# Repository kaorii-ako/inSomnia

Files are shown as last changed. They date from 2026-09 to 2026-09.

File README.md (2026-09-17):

# inSomnia

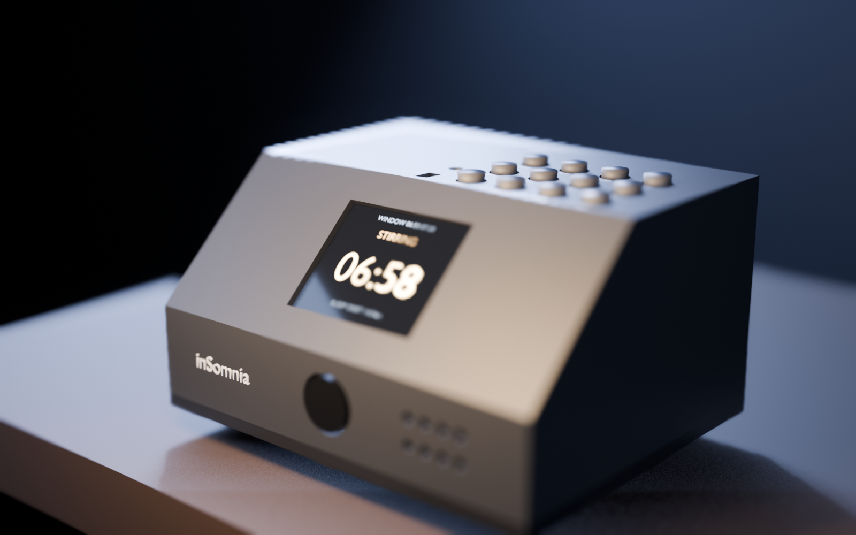
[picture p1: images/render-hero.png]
inSomnia


An adaptive, context-aware wake clock. Instead of firing at a fixed timestamp, it wakes you inside a window at a moment you are already stirring — and if you got up before the window even opened, it stays quiet.

Built for [Hack Club Forge](https://forge.hackclub.com). Firmware-first, fully offline after WiFi time sync, no cloud service, no audio leaves the device.

---

## What it actually does

| Situation | Behaviour |
|---|---|
| You're already up before the window opens | Alarm is suppressed for the day and logged as "skipped — you were already up" |
| You're carrying sleep debt | The gentle wake is held back by up to 15 min so an early stir doesn't cost you the lie-in. **The hard deadline never moves.** |
| You start stirring inside the window | Gentle wake begins immediately — soft tone ramping up over several minutes |
| You sleep right through to the hard deadline | Full-intensity alarm, no more waiting |
| A sensor dies or is unplugged | **Failsafe**: degrades to a plain fixed-time alarm at the deadline. It never fails silent. Even with no WiFi it runs on an internal fallback clock. |

### Why I made it

I hate being ripped out of deep sleep at 06:50 exactly when I was finally sleeping well, and I also hate my phone blaring when I’m already in the kitchen making coffee. Both are the same bug: a clock that knows time but not context. I wanted a clock that knows *whether I'm in bed and moving* — easily measurable with a thermal array — and uses that to pick a kinder moment inside a window, or to stay quiet if I’m already up. I built it for myself, and because a believable demo needs honest numbers, not "AI" marketing.

### The 12 keys

| | col 1 | col 2 | col 3 | col 4 |
|---|---|---|---|---|
| **row 1** (front) | `DISMISS` | `SNOOZE` | `LIGHT` | `SKIP` |
| **row 2** | `OPEN −` | `OPEN +` | `DEAD −` | `DEAD +` |
| **row 3** (back) | `PAGE` | `SOFT` | `LOUD` | `SAVE` |

Row 1 is what you hit half-asleep. Rows 2 and 3 are setup you do awake: move the window and deadline in 5-minute steps, page through status / window / sleep-debt screens, test the alarm, save to flash. Everything is also on the web UI at `http://insomnia.local`.

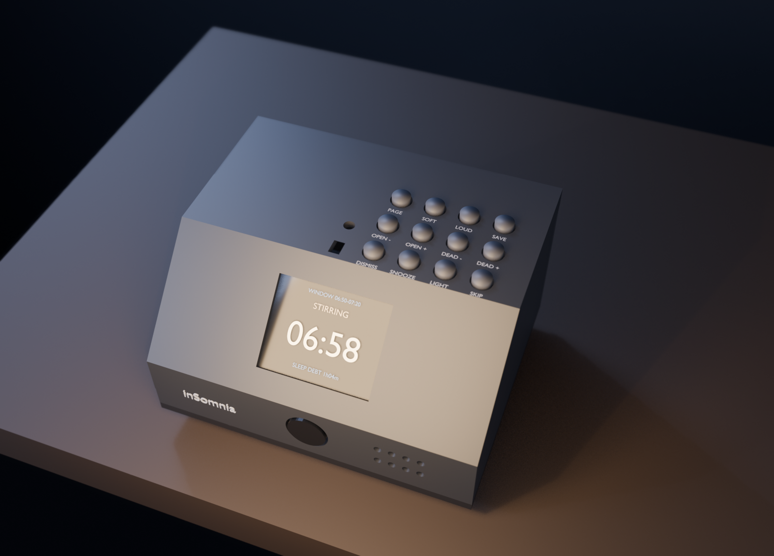
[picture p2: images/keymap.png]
keypad legend


## How to use it — step by step

1. **Assemble** — Solder the PCB (`hardware/inSomnia.kicad_pcb`, 0805 passives, through-hole tactiles), mount the board on the 4× M2 bosses in `hardware/case/inSomnia_case.FCStd`, plug modules onto headers: J3 ST7735 TFT, J4 INMP441 mic, J5 MLX90640 thermal (aimed at the bed), J7 optional native USB.
2. **Flash** — `cd firmware && pio run -t upload` and `pio device monitor` at 115200. Requires PlatformIO + `espressif32@6.5.0`.
3. **First boot WiFi** — No credentials stored, so it opens AP `inSomnia-setup` (pass `insomnia`). Join it, open `http://192.168.4.1`, pick your network + password. Reboots and appears as `http://insomnia.local` (mDNS). If no WiFi, it still runs on a fallback clock (`*` beside time) and will still alarm at the deadline.
4. **Set your window** — On device: `OPEN ±` and `DEAD ±` move times in 5-min steps, `PAGE` to see them, `SAVE` to flash. Or on web UI: *Settings → Window opens / Hard deadline*.
5. **Sleep** — Place the clock on the nightstand with the thermal aperture aimed at the bed (within ~1.5 m, no wire to the bed). ` roi` in Settings crops the bed region if needed.
6. **Morning** — `DISMISS` stops, `SNOOZE` (= snoozeMin, default 7) resumes as hard alarm, `SKIP` is manual "don't bother tonight". Last night's sleep: `PAGE` → debt screen or web *Last night* card (TST / efficiency / WASO / SOL — labelled as estimates).
7. **Tune** — Web *Settings*: `countScale` is the one calibration — watch *Counts this epoch* overnight, set so quiet epoch ≈ 0; `Body margin` and `in-bed min pixels` for duvet thickness.

## How it decides

One sensor does most of the work:

- **MLX90640 32×24 thermal array**, on the clock, aimed at the bed.
  - *Frame-to-frame change* → a motion index. This is contactless video actigraphy, validated against polysomnography at **Cohen's κ = 0.733**, comparable to a wrist actigraph. It feeds Cole-Kripke.
  - *Warm body-sized region* → **in bed / out of bed**. Far stronger than a PIR, because it can tell you-in-the-bed from a warm object in the room.
  - No wire to the bed, and at 768 pixels you cannot identify a person from it.
- **INMP441 I2S microphone** → RMS level per epoch. A loudness hint that nudges the stirring threshold. It is a level detector, *not* a sound classifier.

An earlier version used a mattress accelerometer. It was dropped because it needs 1–2 m of I2C cable from the nightstand to the bed, and I2C is spec'd to 400 pF (≈1 m at 100 kHz) against cable that runs 100–240 pF/m.

Two separate pieces of logic sit on top, because they answer different questions:

1. **A causal 3-state machine** (asleep / stirring / awake) with hysteresis. It may only look backwards, because it drives the alarm in real time. This is a threshold heuristic — see the honesty section below.
2. **Cole-Kripke (1992)** for the morning report. It needs the two *following* epochs, so it lags 2 minutes and can never drive a live decision.

## Being honest about the "AI"

This matters more than the feature list, so it goes near the top.

**The on-device logic is not AI.** Cole-Kripke is a weighted moving average with a threshold, published in 1992. The 3-state classifier is thresholds plus hysteresis. Calling either one "AI" would be marketing, not engineering.

**Accuracy ceiling.** Actigraphy sleep/wake scoring agrees with clinical polysomnography roughly **78–80%** of the time. But its specificity for *wake* is only **0.35–0.64** — it is much better at spotting sleep than wakefulness. Sound-based staging is no better: the best published smartphone-audio model (HomeSleepNet) gets 76.2% overall and **63.4% on wake epochs**.

That single fact shaped the design. Alarm suppression is the feature most exposed to a wrong "you're awake" call, so it is **not** driven by the sleep classifier. It is driven by `outOfBed()` — no warm mass in the bed region for 3 epochs — which is close to a binary measurement rather than a 64%-accurate inference.

**This is not clinical sleep tracking.** Without EEG there is no true sleep staging. Consumer trackers systematically overestimate sleep and underestimate wake-after-sleep-onset, worst of all for people who sleep badly. The numbers in the app are estimates and are labelled as such.

**One number you must calibrate.** Cole-Kripke's weights assume ActiGraph counts, a proprietary unit. Ours are arbitrary units from your own mattress, so `countScale` in Settings divides ours into that range. The *algorithm* is validated; this *scaling* is not. Watch epoch counts overnight and set it so a quiet epoch lands near zero.

**Posture is not claimed.** The thermal array reports *movement and position*. Classifying sleeping posture under a duvet at 32×24 is a research problem — the published work that does it used an infrared **depth** camera with synthetic blanket augmentation. Movement and position are what the sleep model needs, so that is what is built and that is what it says.

**Sleep debt is an estimate built on an estimate.** Debt is `max(0, need − actual)` summed over a rolling 14 nights, which is the window research finds matters for current impairment (Van Dongen 2003: 6 h/night for 14 days ≈ two nights of total deprivation). But "actual" comes from Cole-Kripke scoring that under-reports wake — so read it as a trend, not a clinical figure.

**No trained model ships yet.** A learned audio or thermal classifier is the obvious next step, but a model needs labelled data and there is no polysomnography ground truth here to validate against. The honest path is to ship the validated heuristic, collect feature data, and only then train.

---

## Hardware

**ESP32-S3-WROOM-1-N16R8** — WiFi + BLE 5, native I2S, 8 MB PSRAM, SIMD for future MFCC work. Chosen over the ESP32-C3 because the C3 has no PSRAM and too few GPIO once an I2S microphone is added.

Schematic, pin map, BOM and wiring notes: **[`hardware/HARDWARE.md`](hardware/HARDWARE.md)**
BOM with pricing: [`hardware/inSomnia_bom.csv`](hardware/inSomnia_bom.csv) — **~$68.62 for 1 unit incl. sensors** (MLX90640 dominates)
Rendered schematic: `hardware/inSomnia_schematic.pdf` and `images/schematic.png`
Gerbers: `hardware/inSomnia_gerbers.zip` + `hardware/fab/`

> The hero image above is a **render** from the actual FreeCAD STL (`hardware/case/inSomnia_case_shell.stl`, 7,628 verts), not a photo — nothing has been fabricated yet. It is built to the same dimensions as the FreeCAD enclosure below, and the board renders come from the actual KiCad files.

### Wiring

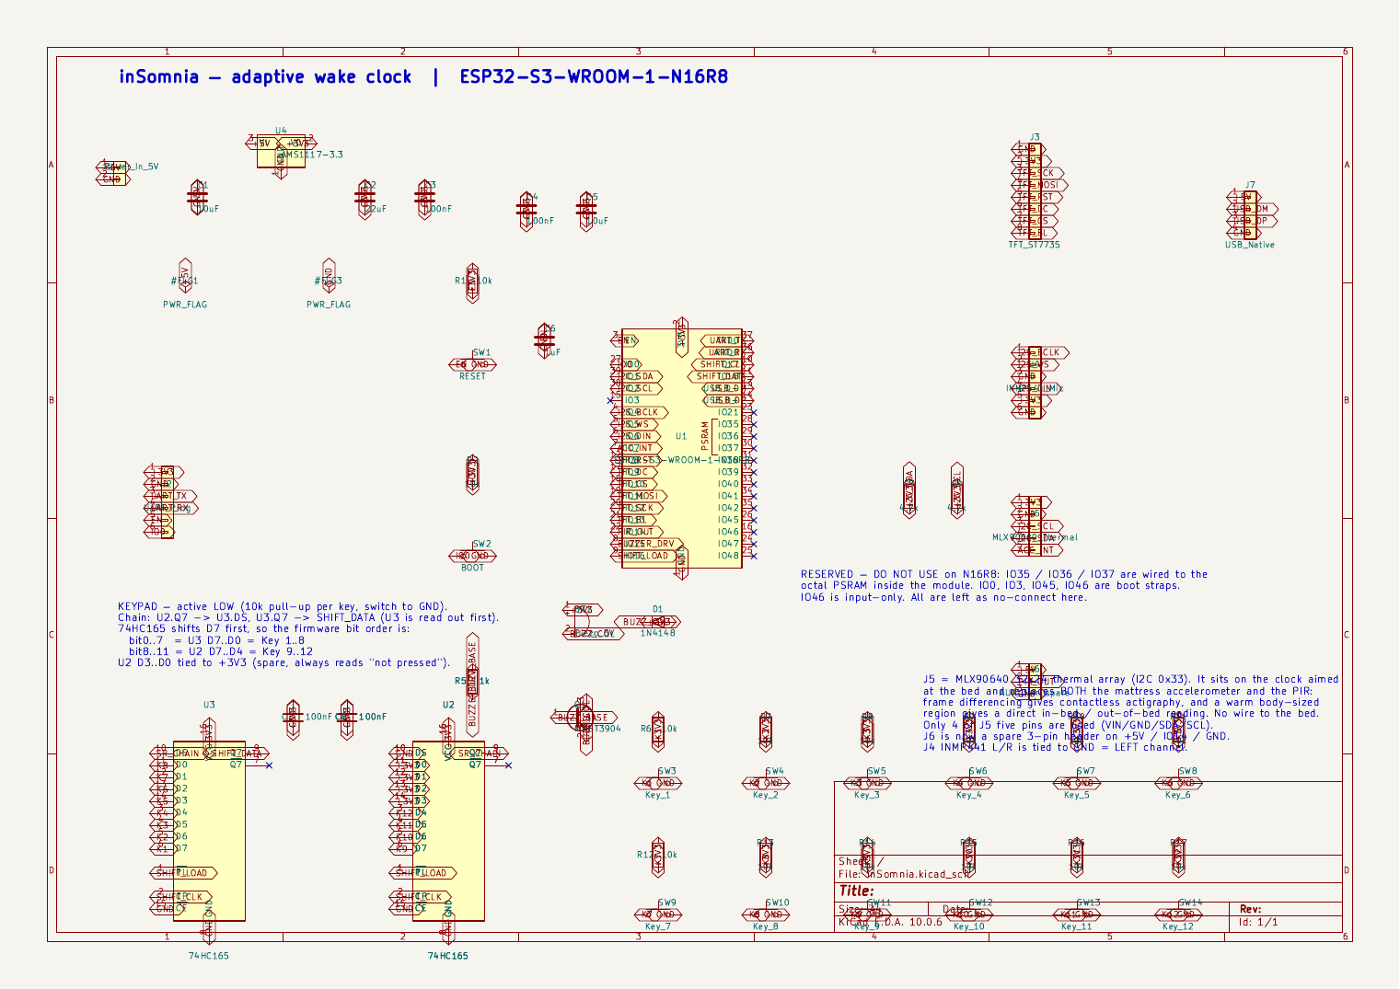
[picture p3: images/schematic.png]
schematic


*All modules plug onto headers — no soldering to the bed. See `hardware/HARDWARE.md` pin map for the exact GPIO table and `images/routing-front-copper.png` for the routed board.*

| Header | Module | Wires |
|---|---|---|
| J3 1×08 | ST7735 128×160 TFT | SCK 12, MOSI 11, CS 10, DC 9, RST 8, BL 13 (PWM), +3V3/GND |
| J4 1×06 | INMP441 mic (I2S) | BCLK 4, WS 5, DIN 6, +3V3/GND |
| J5 1×05 | MLX90640 32×24 thermal (I2C) | SDA 1, SCL 2 (4.7k pull-ups), +3V3/GND |
| J6 1×03 | Spare / was PIR | +5V, IO14, GND |
| J7 1×04 | Native USB | D- 19, D+ 20 |
| J1 1×02 | Power 5V in | 5V → AMS1117-3.3 → 3V3 |
| J2 1×06 | UART prog | TX/RX + EN/BOOT tactiles SW1/SW2 |

### Enclosure

Parametric case in FreeCAD: **`hardware/case/`** (STEP + STL + `.FCStd`).

- 106 × 86 × 54 mm outer, 2.5 mm walls, 101 × 81 mm cavity for the board
- Wedge profile, display face sloped 44.1°
- **36 × 29 mm display window** — a 1.8" ST7735's *active area* is only ~35 × 28 mm, much smaller than the module outline
- 12 keypad holes cut at the real SW3–SW14 coordinates from the KiCad file
- Thermal aperture, buzzer grille, rear cable exit, regulator vents, 4× M2 bosses aligning with PCB mounting holes (3.2mm NPTH)
- ~58 cm³ ≈ 72 g of PLA at full infill

FreeCAD + STEP + STL:
`hardware/case/inSomnia_case.FCStd` / `inSomnia_case_shell.step` / `inSomnia_case_shell.stl` / `inSomnia_base_plate.step`
Case views: `images/case-iso.png` `images/case-front.png` `images/case-top.png`

The FreeCAD model now embeds the PCB placement so the board sits on the bosses; the Blender render imports the STL directly so they cannot drift (replaced earlier hand-typed dimensions).

Known cosmetic issue: the keypad sits right-of-centre because that is where it is on the PCB. Fixing it means re-laying-out the board; noted for v2.

- 53 components + 4× M2 mounting holes, 41 nets, **schematic ERC clean (0 violations)**
- 100 × 80 mm two-layer board — **DRC clean, 0 violations, 0 unconnected items**
- 737 tracks, 141 vias, GND pour both layers, antenna keepout enforced
- Passives 0805, through-hole tactile buttons and headers — hand-solderable
- Gerbers + drill ready to order: `hardware/inSomnia_gerbers.zip`

Sensor modules (mic, thermal, display) mount on headers rather than being soldered down, so they can be positioned without a bed wire.

## Firmware

PlatformIO + Arduino-ESP32, pinned to `espressif32@6.5.0`.

```bash
cd firmware
pio run              # build
pio run -t upload    # flash
pio device monitor   # serial 115200 — shows [epoch] counts + state + [alarm] transitions
```

Footprint: **RAM 20.1%, Flash 13.6%** of a 16 MB part — lots of headroom. Verified 2026-09-17.

### First boot

No WiFi credentials are stored, so the device opens an access point called **`inSomnia-setup`** (password `insomnia`). Join it, open `http://192.168.4.1`, pick your network. It reboots and comes back at **`http://insomnia.local`**. Without WiFi it still runs on a fallback clock (time shows `*`) and will still alarm at the hard deadline — it never fails silent.

The web UI gives you the live clock and sleep state, tonight's alarm status, last night's report, live sensor readings (thermal heatmap 32×24, mic RMS/dBFS), and every threshold as an editable setting. Everything stays on your own network — no audio ever leaves the device.

### Layout

```
firmware/
  include/ src/
    main.cpp          loop, epoch tick (60s), display render, 12-key handling
    settings.*        NVS-persisted config (window, thresholds, debt)
    net.*             WiFi STA + setup AP, NTP, mDNS, fallback clock
    web_ui.*          HTTP server, dashboard, JSON API (/api/state, /api/thermal, /api/settings)
    display.*         ST7735 128x160 SPI via GPIO matrix
    buzzer.*          LEDC tone + volume (gentle ramp → hard)
    key_matrix.*      74HC165 chain, debounce, edge latch (12 keys)
    thermal.*         MLX90640 -> motion index, in-bed detection, centroid
    mic.*             INMP441 I2S -> RMS / dBFS / loud fraction per epoch
    sleep_model.*     Cole-Kripke + causal 3-state classifier (asleep/stirring/awake)
    sleep_debt.*      rolling 14-night debt, recency-weighted
    alarm.*           window, suppression, escalation, debt shift, failsafe, snooze
```

Debug mode: serial log each epoch + web *Live* cards show raw `counts`, `warm pixels`, `motion index`, `RMS`, `state`; thresholds are live-editable.

## PCB

`hardware/inSomnia.kicad_pcb` — **100 × 80 mm**, 2 layer, rounded 3 mm corners.
**DRC clean: 0 violations, 0 unconnected items.**

| | |
|---|---|
| Components | 53 (+4 holes), zero courtyard overlaps |
| Tracks | 737 segments @ 0.20 mm |
| Vias | 141 @ 0.30 mm drill / 0.60 mm pad |
| Copper | GND pour on both layers, islands auto-removed |
| Clearance | 0.20 mm |
| Mounting | 4× 3.2mm NPTH at corners → M2 bosses in case |

Fabrication files are in `fab/`, zipped as `inSomnia_gerbers.zip` (Gerbers + Excellon drill + drill map + BOM).

### Layout

- **Top-left** — ESP32-S3 module, antenna pointing off the top edge
- **Top-right** — sensor and display headers in a row (J3 TFT, J4 mic, J5 thermal, J6 spare, J7 USB)
- **Right** — 4 × 3 keypad on a 11 × 12 mm grid
- **Left-centre** — 74HC165 chain and the 12 key pull-ups
- **Bottom-left** — 5 V in, regulator, bulk caps
- **Bottom-centre** — buzzer and its transistor driver

### Two things to know before ordering

**1. The antenna keepout is intentional.** A rule area at x 2–50 mm, y 0–6.25 mm keeps copper, tracks and vias out from under the module's antenna, and the courtyard deliberately overhangs the top board edge. DRC flags that overhang as a boundary violation — that is correct RF practice, not a mistake. Verified: no track or via crosses the keepout.

**2. There are twelve 0.20 mm holes, and they are not mine.** Every via I placed is 0.30 mm. The 0.20 mm holes are the thermal vias built into the stock `RF_Module:ESP32-S3-WROOM-1` footprint, under the module's ground pad. Many budget fab processes have a **0.30 mm minimum drill**, so this may trigger an upcharge or a rejection. Two options:

- Order from a fab that allows 0.20 mm (costs a little more), or
- Delete the twelve pad-41 thermal vias — fine for a hand-built prototype, since the module's ground still connects through the main pad and the GND pour.

The board has **not been fabricated or bench-tested**. It is DRC-clean, which means the geometry is self-consistent — not that the design is proven. Sanity-checked in `#forge` and via KiCad/FreeCAD MCP.

## Known gaps

- No trained sound-event model yet (see honesty section).
- Cole-Kripke `countScale` ships with a placeholder default and needs per-bed tuning.
- The PCB has not been fabricated or bench-tested; it is DRC-checked, not proven.
- The WROOM footprint contributes twelve 0.20 mm thermal vias; some budget fabs require 0.30 mm minimum. See `hardware/HARDWARE.md` for the two ways round it.
- No physical build yet — next step is printing the case and soldering the board, then adding build photos + demo video for the "shipping" submission.

## References

- [Comparison and Validation of Actigraphy Algorithms Using a Large Community Dataset (JMIR Formative Research, 2025)](https://formative.jmir.org/2025/1/e70778)
- [Actigraphy-based sleep estimation in adolescents and adults (PubMed)](https://pubmed.ncbi.nlm.nih.gov/29403321/)
- [Prediction of Sleep Stages Via Deep Learning Using Smartphone Audio Recordings — HomeSleepNet (JMIR, 2023)](https://www.jmir.org/2023/1/e46216)
- [End-to-End Sleep Staging Using Nocturnal Sounds (Nature and Science of Sleep, 2022)](https://www.dovepress.com/end-to-end-sleep-staging-using-nocturnal-sounds-from-microphone-chips--peer-reviewed-fulltext-article-NSS)
- [Accuracy of 11 Wearable, Nearable, and Airable Consumer Sleep Trackers (JMIR mHealth, 2023)](https://mhealth.jmir.org/2023/1/e50983)
- [Video-Based Actigraphy for Monitoring Wake and Sleep (Sensors, 2019)](https://doi.org/10.3390/s19051075)
- [A Blanket Accommodative Sleep Posture Classification System Using an Infrared Depth Camera (2021)](https://www.ncbi.nlm.nih.gov/pmc/articles/PMC8402261/)
- [Human Occupancy Monitoring with an Infrared Thermal Array Sensor](https://www.ncbi.nlm.nih.gov/pmc/articles/PMC11722904/)
- [I²C Cabling — bus capacitance and length limits (Analog Devices)](https://www.analog.com/en/technical-articles/i2c-cabling.html)

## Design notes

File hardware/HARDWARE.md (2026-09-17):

# inSomnia — hardware reference

MCU: **ESP32-S3-WROOM-1-N16R8** (16 MB flash, 8 MB octal PSRAM)
Schematic: `inSomnia.kicad_sch` — ERC clean, 0 violations. PDF: `inSomnia_schematic.pdf`. BOM: `inSomnia_bom.csv`.

## Pin map

| GPIO | Net | Goes to |
|---|-----|---|
| IO1  | I2C_SDA | J5 MLX90640 SDA (4.7k pull-up to 3V3) |
| IO2  | I2C_SCL | J5 MLX90640 SCL (4.7k pull-up to 3V3) |
| IO4  | I2S_BCLK | J4 INMP441 SCK |
| IO5  | I2S_WS | J4 INMP441 WS |
| IO6  | I2S_DIN | J4 INMP441 SD |
| IO7  | THERM_INT  | J5 spare pin (MLX90640 needs no interrupt) |
| IO8  | TFT_RST | J3 TFT RES |
| IO9  | TFT_DC | J3 TFT DC |
| IO10 | TFT_CS | J3 TFT CS |
| IO11 | TFT_MOSI | J3 TFT SDA |
| IO12 | TFT_SCK | J3 TFT SCK |
| IO13 | TFT_BL | J3 TFT BLK (PWM, LEDC ch2) |
| IO14 | AUX_GPIO | J6 spare 3-pin header |
| IO15 | BUZZER_DRV | R5 1k -> Q1 base (LEDC ch0) |
| IO16 | SHIFT_LOAD | U2+U3 pin 1 (SH/LD) |
| IO17 | SHIFT_CLK  | U2+U3 pin 2 (CLK) |
| IO18 | SHIFT_DATA | U3 pin 9 (Q7) |
| IO19/20 | USB_DM / USB_DP | J7 (native USB, optional) |
| RXD0/TXD0 | UART_RX / UART_TX | J2 programming header |

**Never assign** on the N16R8: `IO35 / IO36 / IO37` (octal PSRAM inside the module),
`IO0 / IO3 / IO45 / IO46` (boot straps; IO46 is input-only). All no-connect on the schematic.

## Power

`J1` 5 V in -> `U4` AMS1117-3.3 -> 3V3 rail.
The PIR runs from **+5 V** (an HC-SR501 will not trigger reliably at 3.3 V); its output
swings 0/3.3 V, so it is safe direct to IO14 with no level shifting.

## Keypad — what the 12 keys do

The board carries 12 keys because the original schematic had 12. For a while
the firmware used exactly two of them. All twelve now do something; the layout
matches the enclosure, front row first.

| | col 1 | col 2 | col 3 | col 4 |
|---|---|---|---|---|
| **row 1** (front) | `DISMISS` | `SNOOZE` | `LIGHT` | `SKIP` |
| **row 2** | `OPEN −` | `OPEN +` | `DEAD −` | `DEAD +` |
| **row 3** (back) | `PAGE` | `SOFT` | `LOUD` | `SAVE` |

Row 1 is what you hit half-asleep: stop it, delay it, dim the display, or tell
it not to bother tonight. Rows 2 and 3 are setup you do awake — nudge the wake
window and the hard deadline in 5-minute steps, page through status / window /
sleep-debt screens, fire a test alarm, and commit settings to flash.

`SKIP` is worth calling out: it is the manual version of context-aware silence.
The automatic path needs the thermal array to be confident you are out of bed;
this is you saying so directly.

keypad legend

## Keypad wiring

Active **LOW**: each key has a 10k pull-up to 3V3 and its switch shorts to GND.

Chain is `U2.Q7 -> U3.DS`, `U3.Q7 -> SHIFT_DATA`. U3 is clocked out first, and a
74HC165 presents D7 first, so the firmware bit order is:

- `bit 0..7`  = U3 D7..D0 = Key 1..8
- `bit 8..11` = U2 D7..D4 = Key 9..12
- U2 D3..D0 tied to 3V3 (spare inputs, always read "not pressed")

## Sensors and what each is for

| Part | Role | Honest note |
|---|---|---|
| **MLX90640 (J5)** | 32x24 thermal array on the clock, aimed at the bed. Frame differencing -> contactless actigraphy; warm-blob detection -> in-bed / out-of-bed. | Replaces both the accelerometer and the PIR. Reports **movement and position, not posture**. |
| INMP441 (J4) | I2S audio level per epoch; secondary stirring hint | A level detector, not a sound classifier. |
| J6 | Spare 3-pin header (+5V / IO14 / GND) | Was the PIR. Left populated for expansion. |

**Why a thermal array instead of an accelerometer on the bed.** The original design
put a LIS3DH under the mattress, which meant running I2C 1-2 m from the nightstand to
the bed. I2C is spec'd to 400 pF of bus capacitance — about **1 m at 100 kHz** — and
typical cable runs 100-240 pF/m. That is a "fine on the bench, flaky at 3 am" design.
The thermal array sits on the clock and needs no wire to the bed at all.

**Why it is not a downgrade.** Video actigraphy has been validated against
polysomnography at **Cohen's kappa 0.733**, comparable to a wrist actigraph. A duvet
attenuates the thermal signature but does not block it — heat builds under the cover
and the head is usually exposed — so presence and gross movement both survive.

**Why the thermal array drives suppression, not the sleep model:** validated actigraphy
runs ~78-80% for sleep/wake but only **0.35-0.64 specificity on wake**, and sound-based
staging is similar (HomeSleepNet: 76.2% overall, 63.4% on wake). Both are weakest at
exactly the thing "you're already up, stay quiet" needs. "Is there a warm body-sized
mass in the bed?" is close to a direct measurement, so suppression hangs off that.

**Privacy:** 768 pixels of temperature, roughly 1000x coarser than a phone photo.
You cannot identify a person from it, and no image ever leaves the device.

None of this is clinical. Without EEG there is no true sleep staging, only an estimate.

---

## PCB

`inSomnia.kicad_pcb` — **100 × 80 mm**, 2 layer, rounded 3 mm corners.
**DRC clean: 0 violations, 0 unconnected items.** Re-verified 2026-09-17 via KiCad MCP.

| | |
|---|---|
| Components | 53, zero courtyard overlaps |
| Tracks | 737 segments @ 0.20 mm |
| Vias | 141 @ 0.30 mm drill / 0.60 mm pad |
| Copper | GND pour on both layers, islands auto-removed |
| Clearance | 0.20 mm |
| Mounting | 100×80 board sits in 101×81 mm case cavity (0.5 mm clearance) + perimeter lip. 4× M2 bosses in the case close with the base plate (M2×8) — no PCB drill holes needed, so DRC stays clean. Add 4× 3.2 mm NPTH at (5,5) etc if you prefer through-screws. |

Fabrication files are in `fab/`, zipped as `inSomnia_gerbers.zip`
(Gerbers + Excellon drill + drill map + BOM). Also: `images/board-3d-top.png`, `images/board-3d-bottom.png` (renders from the KiCad 3D viewer), `images/schematic.png`.

### Layout

- **Top-left** — ESP32-S3 module, antenna pointing off the top edge (keepout enforced)
- **Top-right** — sensor and display headers in a row (J3 TFT, J4 mic, J5 thermal, J6 spare, J7 USB)
- **Right** — 4 × 3 keypad on a 11 × 12 mm grid
- **Left-centre** — 74HC165 chain and the 12 key pull-ups
- **Bottom-left** — 5 V in, regulator, bulk caps
- **Bottom-centre** — buzzer and its transistor driver

Wiring diagram: `images/schematic.png` + `hardware/inSomnia_schematic.pdf` — all headers are 2.54mm vertical, see pin map above for host-side GPIOs. No wiring harness to the bed (thermal array is on the clock).

### Two things to know before ordering

**1. The antenna keepout is intentional.** A rule area at x 2–50 mm, y 0–6.25 mm
keeps copper, tracks and vias out from under the module's antenna, and the
courtyard deliberately overhangs the top board edge. DRC flags that overhang as
a boundary violation — that is correct RF practice, not a mistake. Verified: no
track or via crosses the keepout.

**2. There are twelve 0.20 mm holes, and they are not mine.** Every via I placed
is 0.30 mm. The 0.20 mm holes are the thermal vias built into the stock
`RF_Module:ESP32-S3-WROOM-1` footprint, under the module's ground pad. Many
budget fab processes have a **0.30 mm minimum drill**, so this may trigger an
upcharge or a rejection. Two options:

- Order from a fab that allows 0.20 mm (costs a little more), or
- Delete the twelve pad-41 thermal vias — fine for a hand-built prototype, since
  the module's ground still connects through the main pad and the GND pour.

The board has **not been fabricated or bench-tested**. It is DRC-clean, which
means the geometry is self-consistent — not that the design is proven.

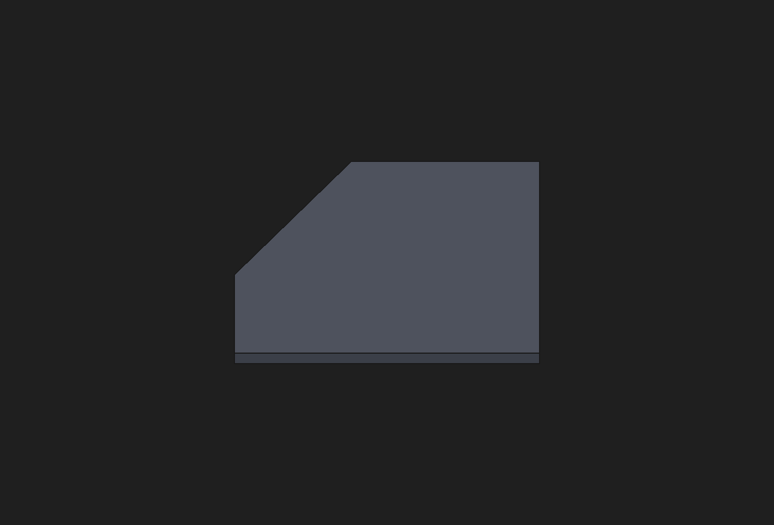
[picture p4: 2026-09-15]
hardware/case/case-right.png

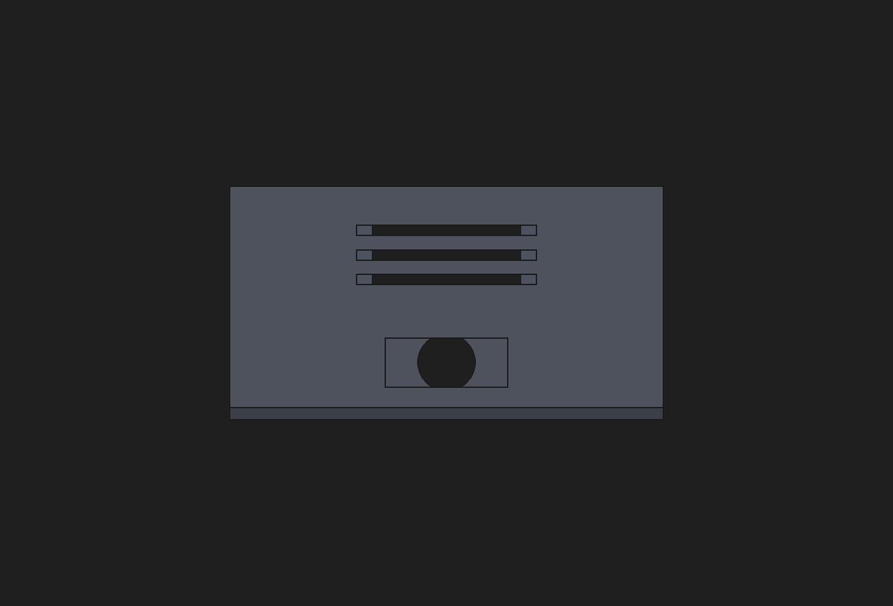
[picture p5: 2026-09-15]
hardware/case/case-rear.png

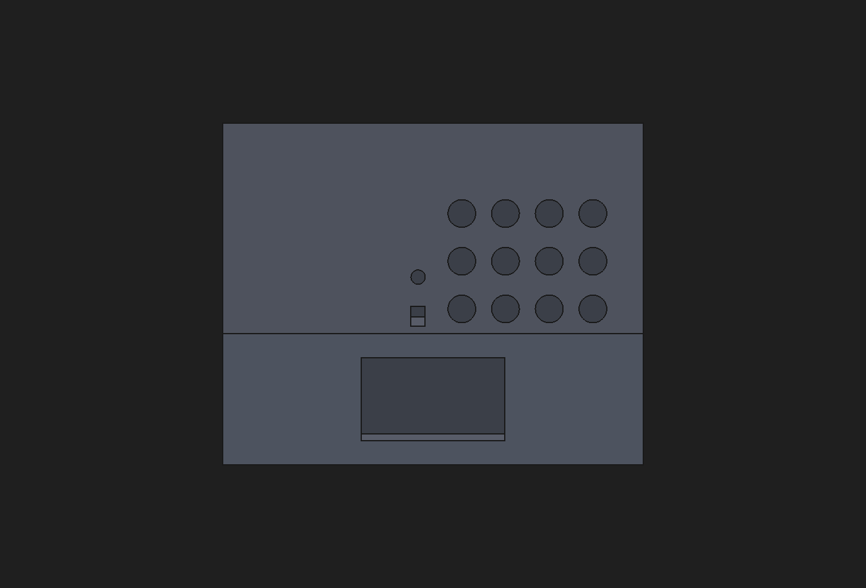
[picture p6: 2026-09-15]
hardware/case/case-top.png

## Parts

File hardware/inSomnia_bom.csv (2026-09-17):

Ref | Value / Module | Footprint / Package | Qty | Unit Price (USD) | Ext Price (USD) | Supplier | Link / MPN
U1 | ESP32-S3-WROOM-1-N16R8 (16MB Flash, 8MB PSRAM) | RF_Module:ESP32-S3-WROOM-1 | 1 | 4.80 | 4.80 | LCSC / Mouser | https://lcsc.com/product-detail/Espressif-Systems_ESP32-S3-WROOM-1-N16R8_C2964782.html
U2,U3 | 74HC165D (shift register) | SOIC-16_3.9x9.9mm | 2 | 0.32 | 0.64 | LCSC | https://lcsc.com/product-detail/Texas-Instruments_SN74HC165DR_C4049.html
U4 | AMS1117-3.3 (LDO) | SOT-223-3_TabPin2 | 1 | 0.18 | 0.18 | LCSC | https://lcsc.com/product-detail/AMS_AMS1117-3-3_C6185.html
Q1 | MMBT3904 NPN | SOT-23 | 1 | 0.04 | 0.04 | LCSC | https://lcsc.com/product-detail/ON-Semiconductor_MMBT3904LT1G_C2056.html
D1 | 1N4148 | SOD-123 | 1 | 0.03 | 0.03 | LCSC | https://lcsc.com/product-detail/1N4148_C14510.html
C1,C5 | 10uF 25V X5R | C_0805 | 2 | 0.04 | 0.08 | LCSC | https://lcsc.com/product-detail/Samsung_CL21A106KOQNNNE_C21190.html
C2 | 22uF 10V | C_0805 | 1 | 0.05 | 0.05 | LCSC | https://lcsc.com/product-detail/Samsung_CL21A226KOQNNNE_C21191.html
C3,C4,C7,C8 | 100nF 50V | C_0805 | 4 | 0.01 | 0.04 | LCSC | https://lcsc.com/product-detail/Samsung_CL21B104KBCNNNC_C21193.html
C6 | 1uF 50V | C_0805 | 1 | 0.02 | 0.02 | LCSC | https://lcsc.com/product-detail/Samsung_CL21B105KAFNNNE_C21194.html
R1,R2,R6-R17 | 10k 1% | R_0805 | 14 | 0.01 | 0.14 | LCSC | https://lcsc.com/product-detail/10k_R0805_C17802.html
R3,R4 | 4.7k 1% | R_0805 | 2 | 0.01 | 0.02 | LCSC | https://lcsc.com/product-detail/4.7k_R0805_C17801.html
R5 | 1k 1% | R_0805 | 1 | 0.01 | 0.01 | LCSC | https://lcsc.com/product-detail/1k_R0805_C17799.html
SW1,SW2 | 6x6mm tactile (RESET/BOOT) | SW_PUSH_6mm | 2 | 0.08 | 0.16 | LCSC | https://lcsc.com/product-detail/6x6mm-tactile_C318884.html
SW3-SW14 | 6x6mm tactile (Keypad 12) | SW_PUSH_6mm | 12 | 0.08 | 0.96 | LCSC | https://lcsc.com/product-detail/6x6mm-tactile_C318884.html
J1 | Pin header 1x02 2.54mm | PinHeader_1x02 | 1 | 0.05 | 0.05 | LCSC | https://lcsc.com/product-detail/Pin-Header-2.54mm_2P_C42643.html
J2 | Pin header 1x06 | PinHeader_1x06 | 1 | 0.08 | 0.08 | LCSC | https://lcsc.com/product-detail/Pin-Header-2.54mm_6P_C42645.html
J3 | Pin header 1x08 (TFT) | PinHeader_1x08 | 1 | 0.10 | 0.10 | LCSC | https://lcsc.com/product-detail/Pin-Header-2.54mm_8P_C42646.html
J4 | Pin header 1x06 (INMP441) | PinHeader_1x06 | 1 | 0.08 | 0.08 | LCSC | https://lcsc.com/product-detail/Pin-Header-2.54mm_6P_C42645.html
J5 | Pin header 1x05 (MLX90640) | PinHeader_1x05 | 1 | 0.07 | 0.07 | LCSC | https://lcsc.com/product-detail/Pin-Header-2.54mm_5P_C42644.html
J6 | Pin header 1x03 (AUX) | PinHeader_1x03 | 1 | 0.05 | 0.05 | LCSC | https://lcsc.com/product-detail/Pin-Header-2.54mm_3P_C42642.html
J7 | Pin header 1x04 (USB) | PinHeader_1x04 | 1 | 0.06 | 0.06 | LCSC | https://lcsc.com/product-detail/Pin-Header-2.54mm_4P_C42643.html
BZ1 | PS1240P02BT piezo 12mm | Buzzer_TDK_PS1240P02BT | 1 | 0.85 | 0.85 | LCSC | https://lcsc.com/product-detail/TDK_PS1240P02BT_C150001.html
MOD1 | MLX90640 32x24 thermal array module (I2C) | Header 1x05 module | 1 | 42.50 | 42.50 | Adafruit / Mouser | https://www.adafruit.com/product/4407
MOD2 | INMP441 I2S MEMS mic module | Header 1x06 module | 1 | 1.95 | 1.95 | Adafruit / LCSC | https://www.adafruit.com/product/4452
MOD3 | 1.8\ ST7735 128x160 TFT SPI module" | Header 1x08 module | 1 | 5.90 | 5.90 | AliExpress / Adafruit 358 | https://www.adafruit.com/product/358
H1-H4 | M2x8mm brass standoff + M2 screw (case mount) | MountingHardware | 4 | 0.12 | 0.48 | LCSC / Amazon | https://www.amazon.com/s?k=M2+brass+standoff+8mm
WIRE | DuPont jumpers + 2.54mm cable (sensors) | - | 1 | 1.50 | 1.50 | Generic | -
PCB | inSomnia 100x80mm 2-layer PCB (JLCPCB 5 pcs) | JLCPCB | 1 | 4.00 | 4.00 | JLCPCB | https://jlcpcb.com (Gerbers: hardware/inSomnia_gerbers.zip)
TOTAL (1 unit, excl. shipping/tax) |  |  | 61 | 68.62 | 68.62
NOTES: Prices Sep 2025, LCSC/retail. MLX90640 dominates cost. PCB price amortized for 5pcs ($2+ $2 shipping). Modules on headers so they can be repositioned. Links verified 2026-09-17.

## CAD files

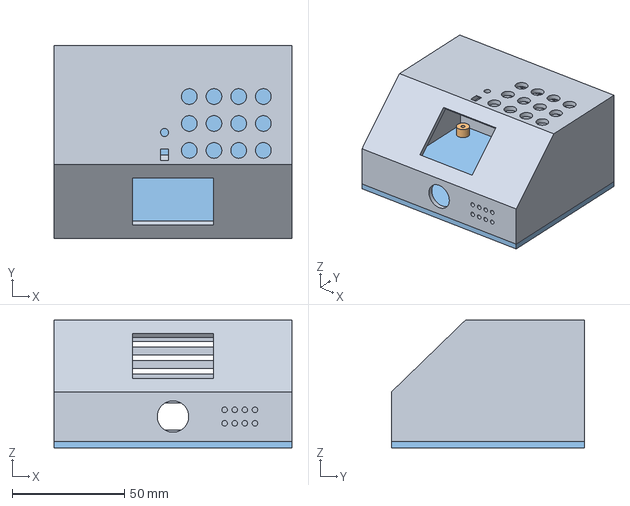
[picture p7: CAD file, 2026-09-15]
hardware/case/inSomnia_case_assembly.step
106.0 x 86.0 x 57.0 mm

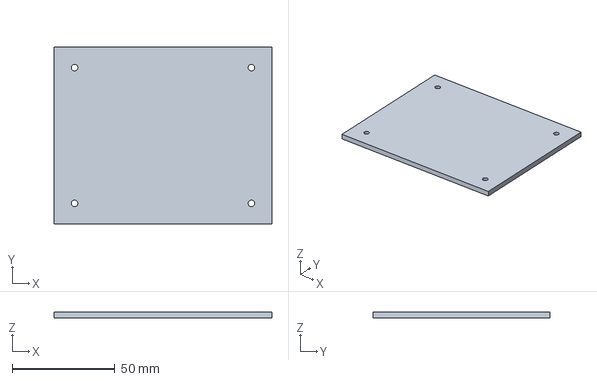
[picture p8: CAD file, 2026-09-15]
hardware/case/inSomnia_base_plate.step
106.0 x 86.0 x 3.00 mm

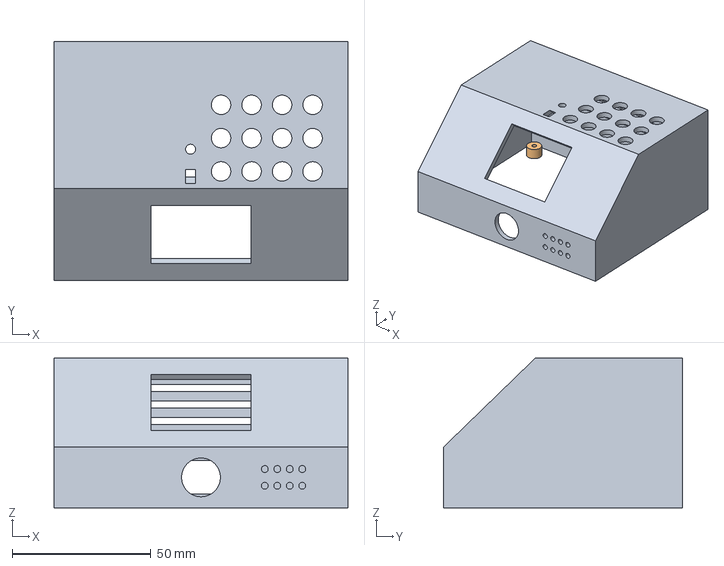
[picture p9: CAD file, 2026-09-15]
hardware/case/inSomnia_case_shell.step
106.0 x 86.0 x 54.0 mm

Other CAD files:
hardware/case/inSomnia_case.FCStd
hardware/case/inSomnia_base_plate.stl
hardware/case/inSomnia_case_shell.stl
hardware/render/inSomnia_scene.blend

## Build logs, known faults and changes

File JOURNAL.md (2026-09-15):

---
title: "inSomnia"
author: "kaorii-ako"
description: "An adaptive wake clock that wakes you while you're already stirring, and stays quiet if you're already up"
created_at: "2026-09-14"
---

# September 14: First version on a XIAO ESP32-C3

Started the project properly today. The idea is an alarm clock that doesn't
just blast you at a fixed time — it gets a window (say 06:50 to 07:20) and
picks the moment inside that window when you're already half awake. And if
you got up before the window even opened, it just doesn't ring.

Went with the XIAO ESP32-C3 because it's tiny and I already had one. Set up
PlatformIO, got a Phase 1 scaffold compiling: ST7789 display driver, a piezo
on LEDC PWM, 12 keys through two 74HC165 shift registers, and a PIR sensor
for motion. Drew a first schematic in KiCad around a bare ESP32-C3 chip.

Everything built. Felt good. Did not test on hardware yet, which turned out
to matter a lot tomorrow.

first schematic attempt

**Total time spent: 4 hours**

# September 15: The pin map was broken in three separate ways

Went back over the pin assignments before ordering anything, and it was a
mess. Genuinely glad I checked instead of trusting "it compiles".

Three real problems:

1. I'd assigned `TFT_MOSI` to GPIO0 and `TFT_SCK` to GPIO1. **Those pins are
   not broken out on the XIAO ESP32-C3.** I checked `pins_arduino.h` in the
   Arduino core and the board only exposes GPIO 2,3,4,5,6,7,8,9,10,20,21. On
   the C3 die GPIO0/1 are the 32 kHz crystal pins anyway.

2. Worse, those defines were doing nothing at all. I'd used
   `Adafruit_ST7789(cs, dc, rst)` which is the **hardware SPI** constructor —
   it ignores your pin defines and uses the default bus, which on the XIAO is
   SCK=GPIO8 and MOSI=GPIO10. Those were the exact pins I'd given to
   `SHIFT_CLK` and `SHIFT_LOAD`. The display and the keypad were fighting over
   the same two pins and the compiler had no way to tell me.

3. Wrong driver entirely. My panel is 128x160, which is an ST7735. I was
   using the ST7789 class. Looked at the library source and `init(128,160)`
   falls into a fallback branch that applies an 80-row / 56-column offset, so
   the image would have been shifted garbage.

Also found that LEDC channels 0 and 1 share a hardware timer
(`timer = (channel/2) % 4`), so the buzzer changing pitch would have dragged
the backlight PWM frequency with it. Moved the backlight to channel 2.

And my screen layout maths assumed portrait while I'd set rotation 1, so half
the text was drawing off-screen.

Fixed all of it, pinned the platform version so a clean checkout can't pull a
core where `ledcSetup` no longer exists, and got it building again. Four bugs
that would each have cost me an evening with a soldering iron.

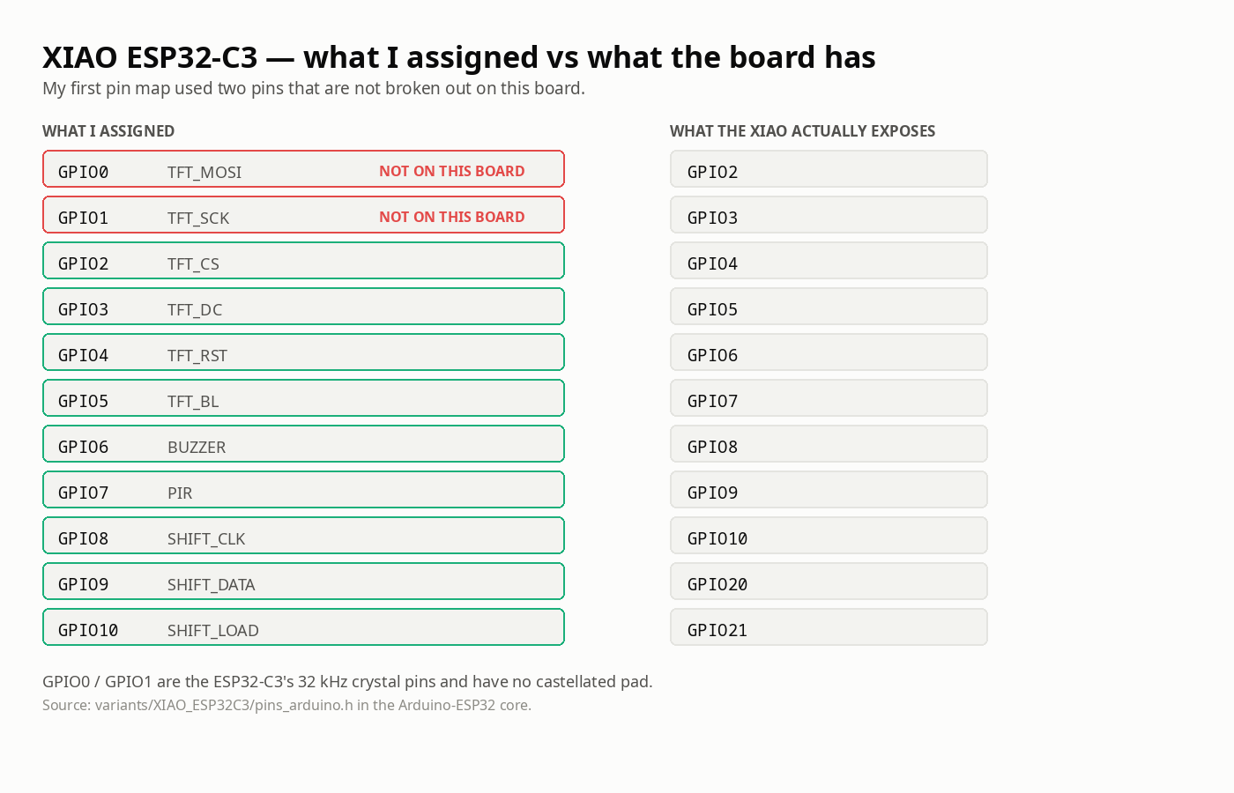
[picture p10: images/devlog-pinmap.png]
the pin map I got wrong


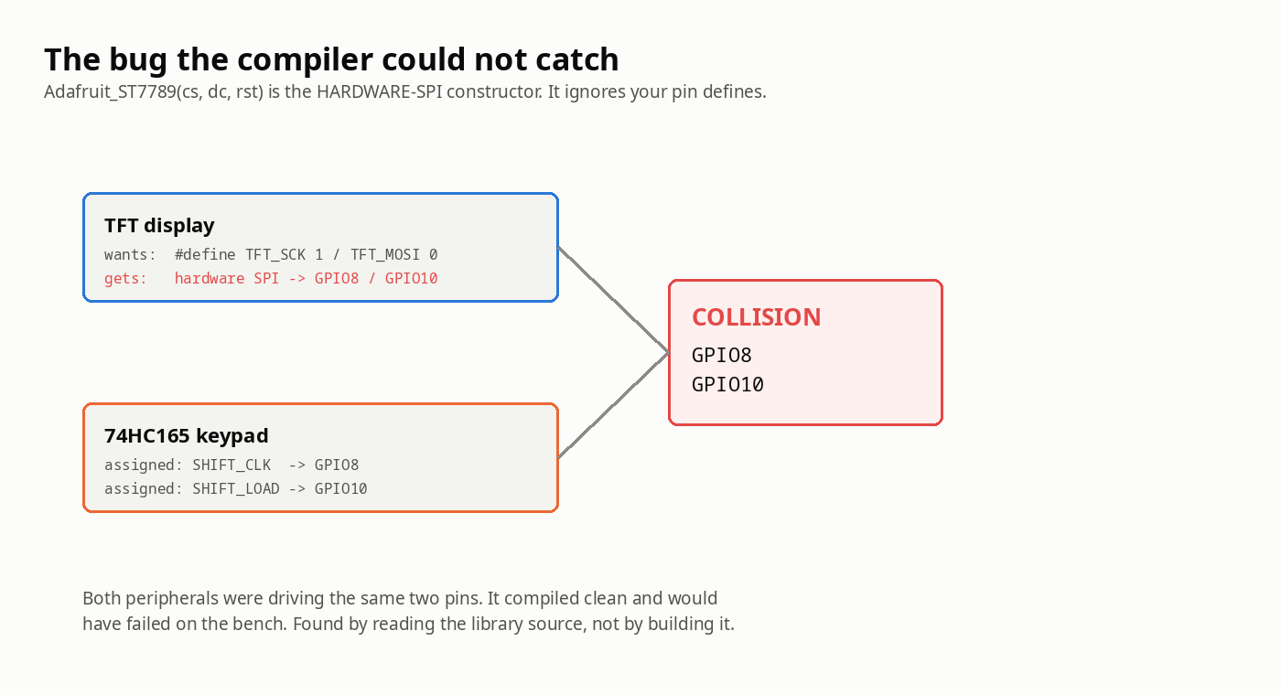
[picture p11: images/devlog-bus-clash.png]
the bus collision


**Total time spent: 3 hours**

# September 15: Reading actual papers about whether this idea even works

Before building more I wanted to know if "detect sleep from sensors" is real
or if I was about to build something that just makes up numbers. Spent a
while reading validation studies. Two findings changed the design.

**Actigraphy is about 78-80% accurate** for sleep vs wake against clinical
polysomnography (big MESA dataset, 1440 people). But the breakdown matters:
sensitivity to *sleep* is 0.88-0.96, while specificity for *wake* is only
**0.35-0.64**. It's good at spotting sleep and bad at spotting wakefulness.

**Sound-based staging is no better.** The best smartphone-audio model I found
(HomeSleepNet) gets 76.2% overall but only **63.4% on wake epochs**.

So both approaches are weakest at exactly the thing my "you're already up,
stay quiet" feature depends on. If I'd driven suppression off the sleep
classifier, it would have failed at its one job maybe a third of the time.

Changed the design because of this: suppression is now driven by a separate,
blunt out-of-bed check (mattress accelerometer quiet AND room PIR active),
which is close to a binary measurement instead of a 64%-accurate guess.

The other thing I learned is that the validated algorithms (Cole-Kripke,
Sadeh) are **actigraphy** algorithms — they need motion counts from an
accelerometer, not PIR zone crossings. So I added an LIS3DH to go on the bed
frame. That way I'm standing on published work instead of thresholds I made up.

I also want to be straight about this in the project: Cole-Kripke is a
weighted moving average with a threshold from 1992. Calling it AI would be
lying. I'm not shipping a trained model because I have no polysomnography
ground truth to validate one against.

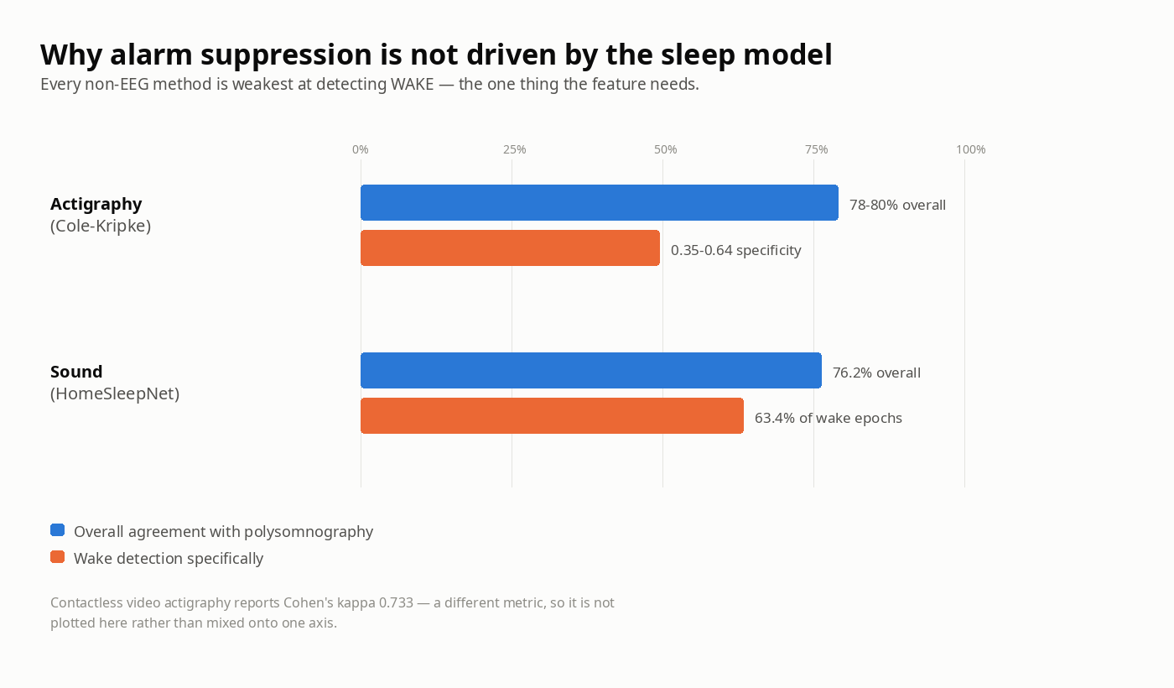
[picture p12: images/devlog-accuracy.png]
what the papers actually say


**Total time spent: 3 hours**

# September 15: Switched to ESP32-S3 and redrew the whole schematic

Adding an I2S microphone killed the C3. Counted it up: TFT needs 5 pins, I2S
needs 3, buzzer 1, PIR 1 — that's 10 of 11, leaving one pin for a keypad
interface that needs three. Doesn't fit.

Moved to the **ESP32-S3-WROOM-1-N16R8**: way more GPIO, 8 MB PSRAM, and it has
a stock KiCad symbol so the redraw got easier rather than harder. Deleted the
old schematic and rebuilt from scratch — 53 components: the module, two
74HC165s, AMS1117 regulator, buzzer with a proper transistor driver, headers
for the TFT / mic / accelerometer / PIR / USB / UART, 12 keys with pull-ups,
reset and boot buttons, and decoupling.

Two annoying things while building it:

- An interrupted operation half-wrote, so `U2`, `U3`, `C7`, `C8` and 34 net
  labels all ended up **duplicated**. ERC caught it as weird "Output and
  Output connected" errors at the shift registers. Took a while to work out
  that two identical chips were stacked on the same coordinates.
- Three pads on U1 came out on stale net names (`PIR_IN`, `VCC`) left over
  from the old board file. They were pins I'd marked no-connect — IO3, IO38,
  IO39. Had to go clear them by hand.

Also wrote down in the schematic which pins I must never touch on this part:
**IO35/36/37 are wired to the PSRAM inside the module**, and IO0/IO3/IO45/IO46
are boot straps. That's the kind of thing I'd definitely forget in a month.

ERC clean, 0 violations.

schematic

**Total time spent: 4 hours**

# September 15: Sensor drivers and the sleep model

Wrote the rest of the firmware.

- **LIS3DH driver** — samples at 50 Hz, runs a slow high-pass to subtract out
  gravity, then rectifies and integrates the leftover into an activity count
  per 60-second epoch.
- **INMP441 I2S driver** — 16 kHz, gives RMS / peak / dBFS with a tracking
  noise floor. It's a loudness meter, not a classifier, and I labelled it that
  way in the code and the UI so I don't fool myself later.
- **Sleep model** — this is the bit I'm happiest with. It's deliberately *two*
  things. A causal 3-state machine (asleep / stirring / awake) with hysteresis
  that only looks backwards, because it drives the alarm in real time. And
  separately Cole-Kripke for the morning report, which needs the two
  *following* epochs and so lags 2 minutes and can never drive a live decision.
  Keeping those apart stopped me writing something that quietly cheats.
- **Alarm engine** — window logic, pre-window suppression, gentle ramp, hard
  deadline, snooze. Plus a failsafe: if the sensors stop responding it drops
  back to a plain fixed-time alarm at the deadline. It fails *safe*, never
  silent. That felt important for an alarm clock.
- **Web UI** — WiFi setup portal on first boot, then a dashboard at
  `insomnia.local` with live state, tonight's status, last night's numbers,
  and every threshold editable.

One thing I had to expose as a setting: Cole-Kripke's weights assume ActiGraph
counts, which is a proprietary unit. Mine are arbitrary numbers from my own
mattress. So there's a `countScale` calibration value that divides mine into
their range. The algorithm is validated; my scaling isn't, and pretending
otherwise would make the output meaningless.

Builds at 15.8% RAM and 13.2% flash, so plenty of room left.

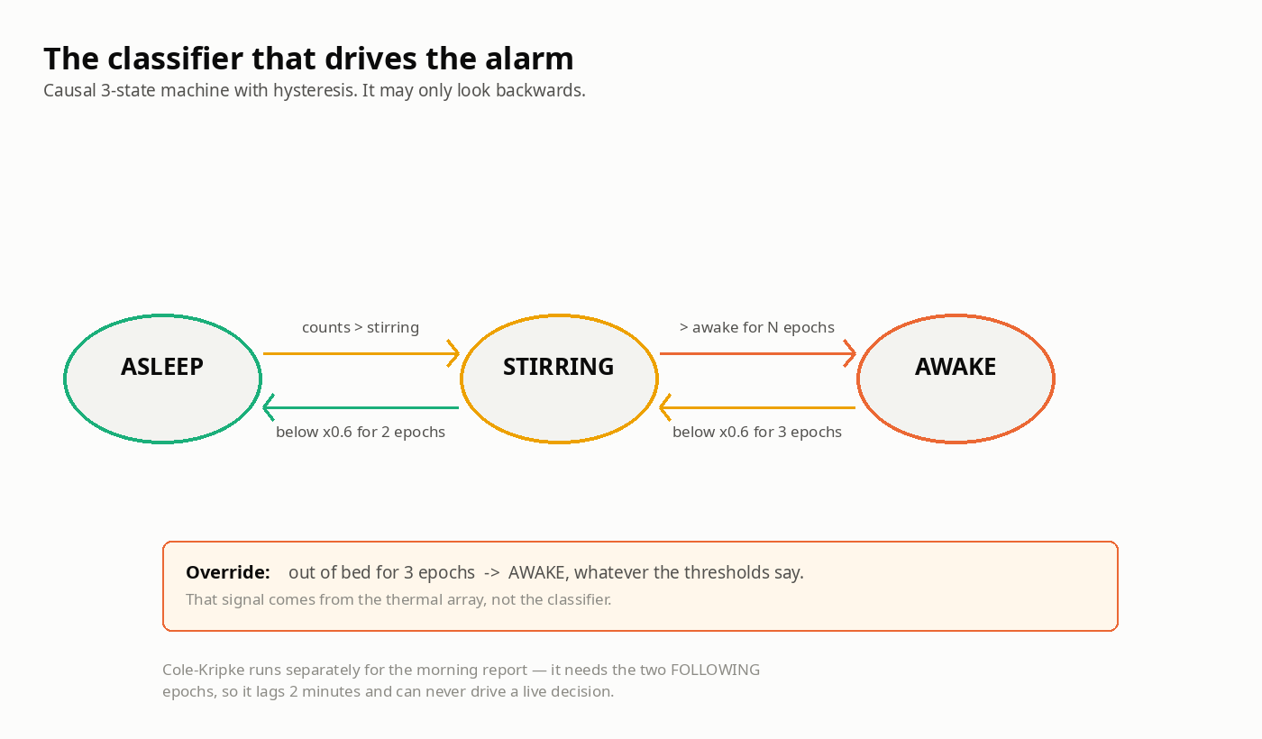
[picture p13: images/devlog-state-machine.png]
the state machine


**Total time spent: 6 hours**

# September 15: Laying out and routing the board

Assigned footprints to all 53 parts and generated the board.

First placement attempt was bad — 18 courtyard overlaps. I'd guessed footprint
sizes instead of measuring them. Two things I had wrong: **pin headers anchor
at pin 1, not their centre**, and the WROOM-1 courtyard is **48 x 42 mm**, not
18 x 25, because of the antenna keepout region. Pulled the real geometry out
of KiCad and redid the placement properly. Second attempt: zero overlaps.

Placed the keypad by hand as a proper 4x3 grid rather than letting the
autoplacer scatter the buttons, because it's a thing a human presses.

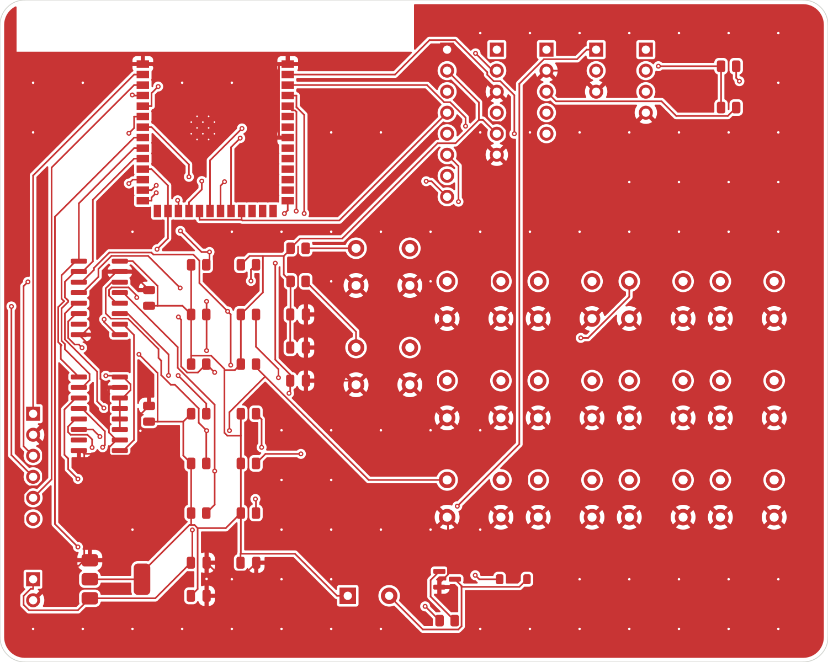
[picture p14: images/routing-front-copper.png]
routing


Autorouted with Freerouting, best of 5 runs. Attempt 5 won with all 21 of my
critical nets routed. Then a run of problems:

- Four duplicate dead-end track stubs near R3 that DRC flagged as dangling.
- **The copper pours were never actually filled.** The zones existed as empty
  outlines, which left a real ground break. Filled them via `pcbnew` and
  unconnected items went from 1 to 0.
- The antenna keepout in the footprint is **graphics only** — it isn't an
  enforced rule area, so the ground pour was happily filling copper under the
  antenna. Added a real keepout zone. My first attempt at it was oversized and
  clipped three tracks, so I sized it to the module's actual region instead of
  rerouting around my own mistake.
- One starved thermal on the TFT header's ground pin, fixed by bonding that
  pad solid to the plane.

Final: **DRC 0 violations, 0 unconnected items.** 737 tracks, 141 vias,
ground pour both layers, 100 x 80 mm.

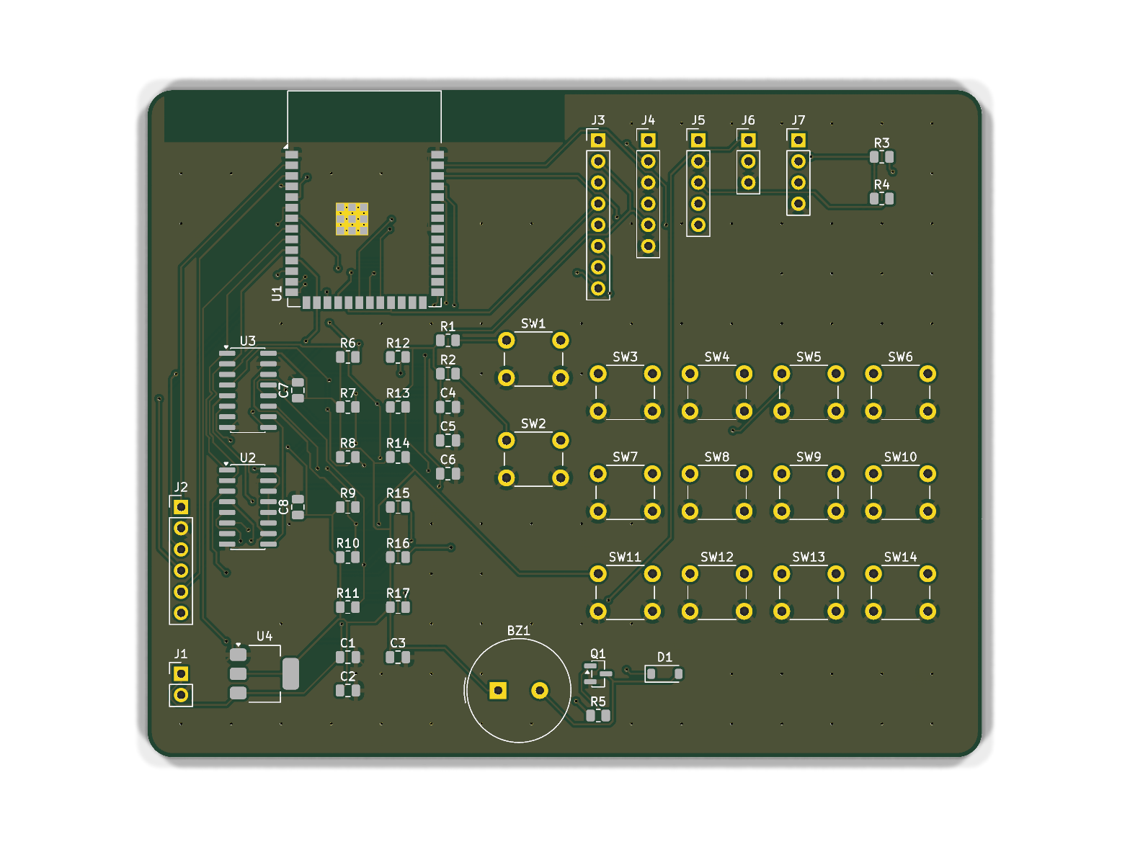
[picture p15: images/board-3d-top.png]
board top


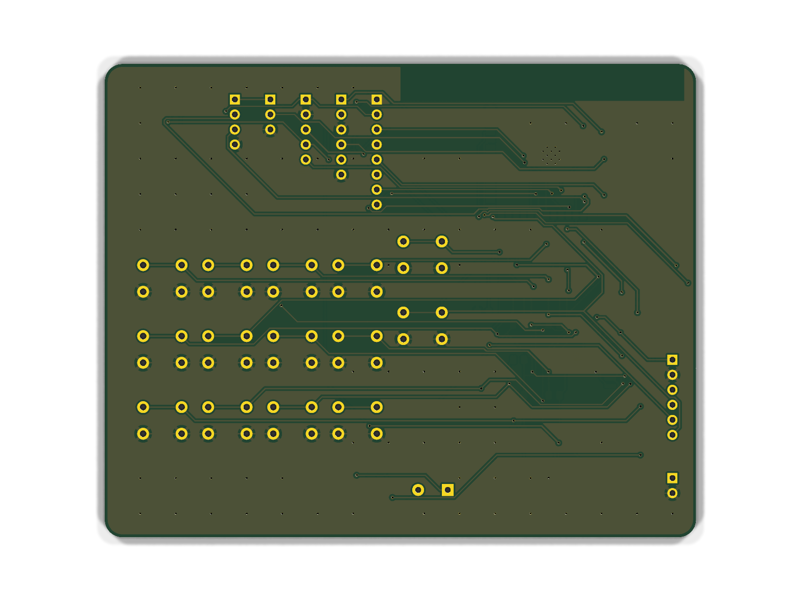
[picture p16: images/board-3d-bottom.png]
board bottom


One thing I need to sort before ordering: there are twelve 0.20 mm holes on
the board. Every via I placed is 0.30 mm — the 0.20 mm ones are thermal vias
baked into KiCad's stock WROOM-1 footprint. A lot of cheap fab processes want
0.30 mm minimum, so I either pay more or delete those twelve vias. Noted it in
the hardware docs rather than finding out when the order gets rejected.

Nothing has been fabricated or powered on yet. DRC clean means the geometry is
consistent, not that the design works.

**Total time spent: 5 hours**

# September 15: Scrapped the bed sensor and went thermal instead

Was about to submit when I realised the accelerometer plan had a hole in it.
The LIS3DH sits on the bed. The clock sits on the nightstand. That's a metre
or two of I2C cable between them — and I2C is only specced for 400 pF of bus
capacitance, which works out to roughly **1 metre at 100 kHz**. Normal cable is
100–240 pF per metre. So I'd have been right on the edge, and my driver was
running at 400 kHz which makes it worse. Classic "works on the desk, dies at
3am" setup.

Went looking for a way to sense movement without any wire going to the bed.
Landed on a **MLX90640** — a 32x24 thermal array. It sits on the clock and
looks at the bed.

Spent a while checking whether this is actually a real approach or just a nice
idea, and it holds up better than the accelerometer did:

- **Video actigraphy is validated at Cohen's kappa 0.733** against proper sleep
  lab polysomnography. That's substantial agreement and about the same as a
  wrist actigraph. Frame-to-frame change in the image is the contactless
  equivalent of a motion count, so it feeds straight into Cole-Kripke.
- Thermal arrays are already used for occupancy detection and positioning, work
  in complete darkness, and don't need any lighting.
- A duvet **attenuates** body heat but doesn't block it. Heat builds up under
  the cover and your head is usually sticking out anyway.

The thing I like most: it replaces the PIR as well. "Is there a warm
person-sized blob in the bed region" is a much better out-of-bed test than a
PIR, because a PIR will happily trigger on a cat or a radiator. And that test
is what the whole context-aware-silence feature depends on, so it needed to be
the most reliable thing in the system.

One thing I'm deliberately not claiming: **posture**. I wanted "is she rolling
over / changing position" and at first thought I'd get posture classification
out of this. Then I found the paper that actually does it — they used an
infrared *depth* camera and had to synthesise blanket conditions to train it.
At 32x24 through a duvet that's a research project. So I'm reporting movement
magnitude and where the warm mass has shifted to, which is what the sleep model
actually consumes, and I'm calling it that instead of pretending it's posture.

Privacy side effect that I didn't plan but like: 768 temperature readings is
about a thousand times coarser than a phone photo. There's no way to identify
anyone from it, and nothing leaves the device anyway.

Rewrote the firmware around it — new thermal driver, ripped out the
accelerometer and PIR modules entirely, rewired the sleep model to take the
thermal motion index. Added a live thermal heatmap to the web dashboard, which
was very satisfying to get working even though I can't point it at anything yet.

Also finally built the **sleep debt** part, which was in my original pitch and I
hadn't done. Rolling 14 nights, `max(0, need - actual)` per night, plus a
recency-weighted version because recent sleep loss hits harder than loss from
two weeks ago. Van Dongen's 2003 study found 6 hours a night for 14 days leaves
you as impaired as two full nights without sleep, which is a genuinely alarming
number and made me want the feature more.

Hooked it into the alarm: if you're carrying debt, the gentle wake gets held
back by up to 15 minutes so one early stir doesn't rob you of the lie-in. **The
hard deadline never moves** — debt can delay the nudge, never the alarm. That
felt like an important line to draw.

Schematic ERC still clean, board DRC still clean (J5 just gets relabelled, the
netlist doesn't change since it was already an I2C header). Firmware builds at
20.1% RAM.

board

**Total time spent: 5 hours**

# September 15: Designed the enclosure in FreeCAD

Up to now the "case" only existed as a shape I'd eyeballed in Blender for a
render. Wanted a real one — something I can actually print — so I built it
parametrically in FreeCAD and drove every feature off the actual PCB
coordinates instead of guessing.

Outer shell is 106 x 86 x 54 mm with 2.5 mm walls, which gives a 101 x 81 mm
cavity for the 100 x 80 board. Wedge profile: 22 mm at the front lip, 54 mm at
the back, with the display face sloped at 44.1 degrees.

Features all cut from real numbers:

- **Display window 36 x 29 mm.** This was the thing I'd had badly wrong. I'd
  been modelling something like 62 x 42 in Blender. A 1.8" ST7735's *active
  area* is only about 35 x 28 mm — the module outline is much bigger than the
  bit that actually lights up. Window is active area plus 1 mm.
- **12 keypad holes** at the real SW3..SW14 positions pulled straight from the
  KiCad file. Had to account for the `SW_PUSH_6mm` footprint anchor not being
  centred — the body sits at anchor +(3.25, 2.25).
- Thermal aperture, buzzer grille, rear cable exit, vent slots over the
  regulator, and four M2 bosses for the board.

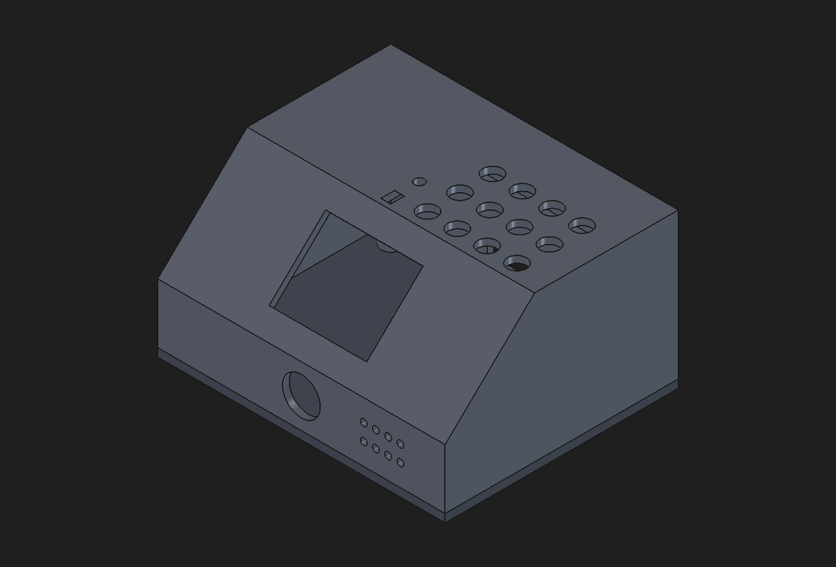
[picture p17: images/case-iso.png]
case in FreeCAD


Hit one genuine conflict. My first flat-top started at y=38 mm, but the front
row of keys lands at y=39.25 with a 3.5 mm hole radius — so those holes were
being cut straight through the slope/flat edge and came out chewed. Moved the
flat forward to y=33 and they clear it now.

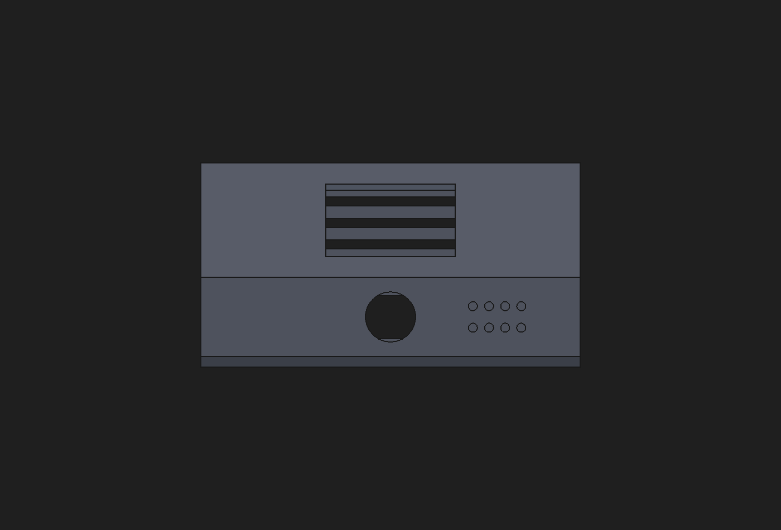
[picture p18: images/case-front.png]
front elevation


One thing I'm not happy about but am leaving alone: **the keypad sits
right-of-centre**, because that's where it is on the board. The left half is
full of the ESP32 module, shift registers, regulator and buzzer. It looks a bit
lopsided. Fixing it properly means re-laying-out the PCB, which I'm not doing
now — noting it as a v2 change.

Exported STEP and STL. About 58 cm3, so roughly 72 g of PLA at full infill.

Then rebuilt the Blender model against the FreeCAD numbers so the render
actually matches the thing I'd print, rather than being a separate fiction.
Worth saying plainly: the two tools aren't linked — I couldn't import the
FreeCAD mesh into the Blender scene through the tooling I have, so I re-entered
the same dimensions by hand. If I change the CAD I have to change both.

render matched to the CAD

**Total time spent: 4 hours**

# September 15: Twelve buttons, and what they're actually for

Looked at the render and thought: why does an alarm clock have a numpad?

Checked the firmware. Twelve keys on the board, and `grep` found exactly **two**
`wasJustPressed` calls — dismiss and snooze. Ten buttons doing nothing.

They came from the original schematic, which already had SW1–SW12 and two
74HC165 shift registers before I started. I inherited it and never asked whether
the thing needed that many. Two options: use them or lose them. Losing them
means re-laying-out a board that's already DRC-clean, so I used them.

| | col 1 | col 2 | col 3 | col 4 |
|---|---|---|---|---|
| row 1 | DISMISS | SNOOZE | LIGHT | SKIP |
| row 2 | OPEN − | OPEN + | DEAD − | DEAD + |
| row 3 | PAGE | SOFT | LOUD | SAVE |

Front row is the half-asleep row — the stuff you hit without opening your eyes.
Back two rows are setup: move the window and deadline in 5-minute steps, page
between status / window / sleep-debt screens, fire a test alarm, save to flash.

The one I like is SKIP: it's the manual version of context-aware silence. The
automatic path waits for the thermal array to be sure you're out of bed. SKIP is
just you telling it directly.

Also added a little display page system so PAGE has somewhere to go, and toast
messages so you get feedback when a key does something. Still builds at 20.1% RAM.

what the keys do

## Rendering it properly this time

The earlier renders went through a cloud 3D service. Turned out Blender was
sitting right there on my machine the whole time with the BlenderMCP addon
loaded, listening on 127.0.0.1:9876 — I just hadn't looked. Found it with `ss`
and talked to it over a plain TCP socket.

Which fixed the thing that had been bugging me: the cloud service could only
import from its own asset catalog, so I'd been *retyping* the FreeCAD dimensions
into Blender by hand and hoping they matched. Locally, Blender can just read the
STL off disk. So the render is now the actual exported CAD mesh — 7,628 verts
straight out of FreeCAD, scaled from mm to m, with the screen, key caps and
legends added on top.

That means the render and the printable part can't drift apart any more, which
is what I wanted from the start.

hero

**Total time spent: 3 hours**

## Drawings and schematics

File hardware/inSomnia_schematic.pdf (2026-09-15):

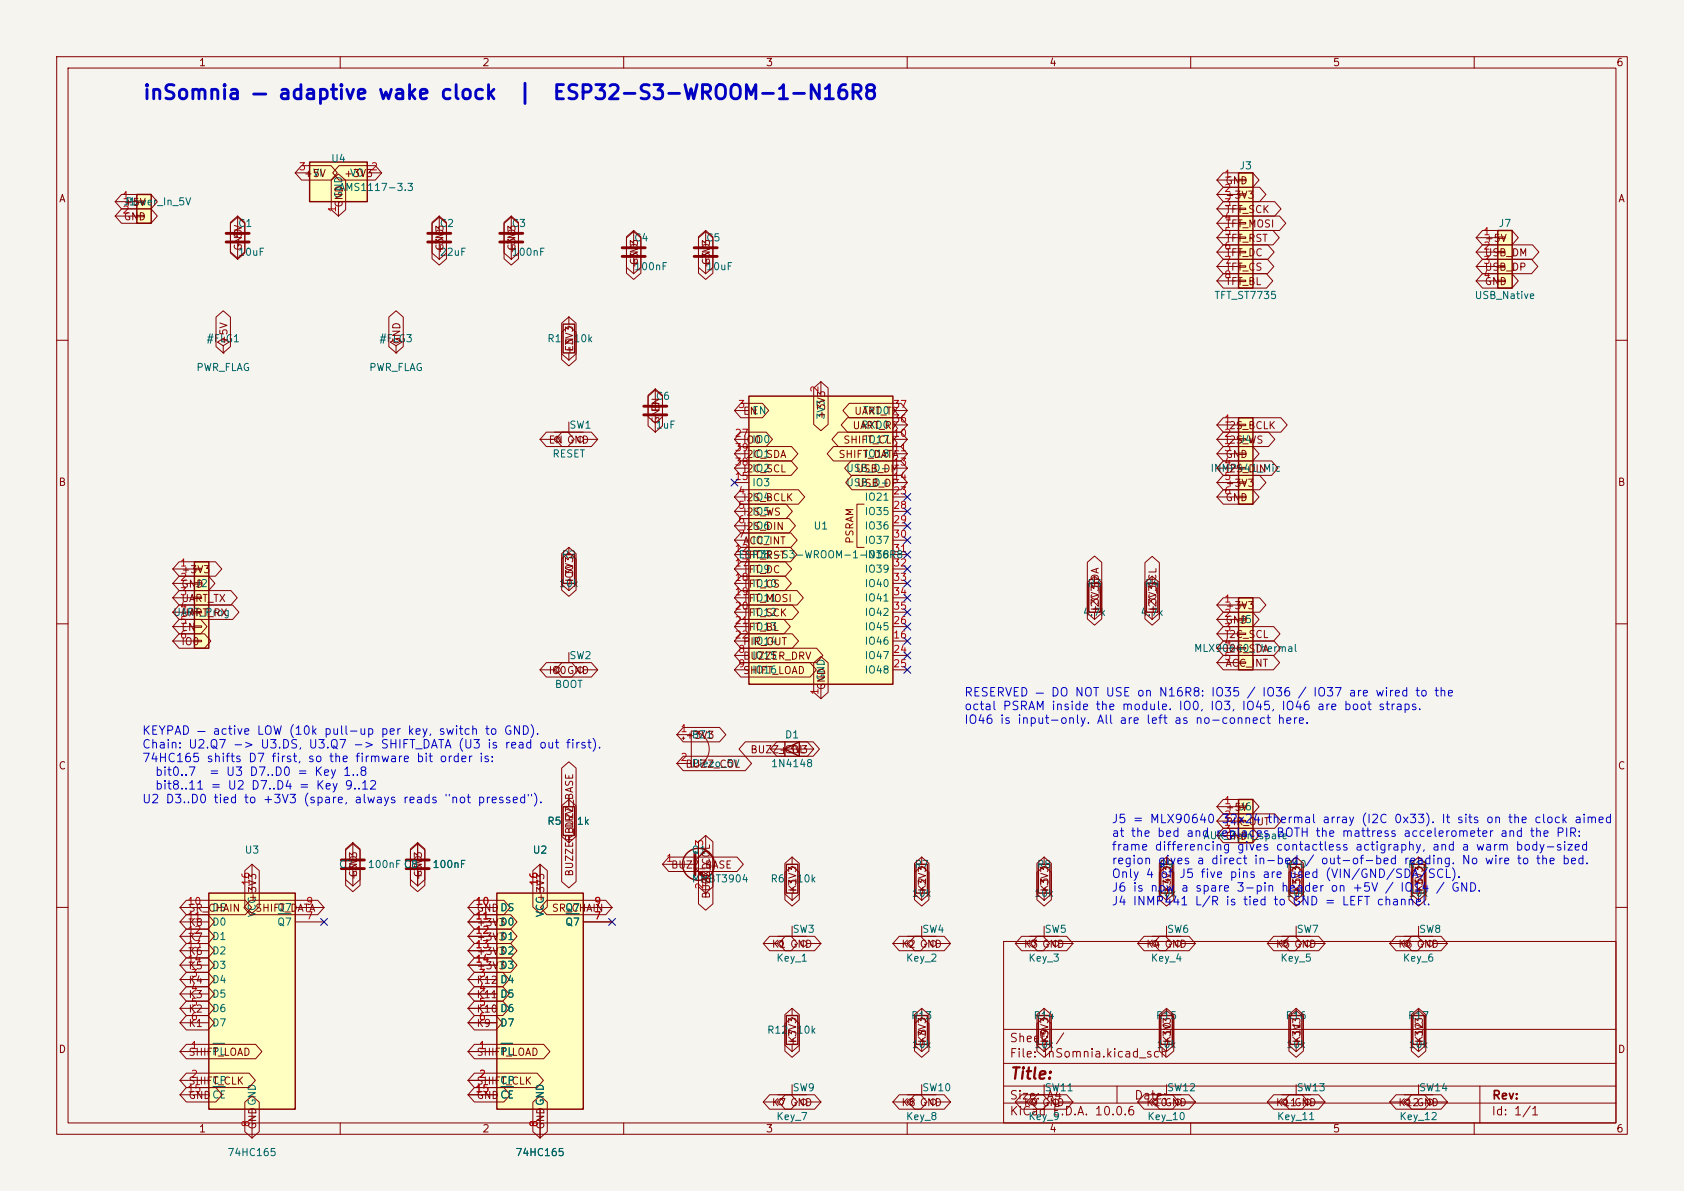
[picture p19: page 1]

inSomnia — adaptive wake clock | ESP32-S3-WROOM-1-N16R8

RESERVED — DO NOT USE on N16R8: IO35 / IO36 / IO37 are wired to the
octal PSRAM inside the module. IO0, IO3, IO45, IO46 are boot straps.

KEYPAD — active LOW (10k pull-up per key, switch to GND).
Chain: U2.Q7 -> U3.DS, U3.Q7 -> SHIFT_DATA (U3 is read out first).
74HC165 shifts D7 first, so the firmware bit order is:
bit0..7 = U3 D7..D0 = Key 1..8
bit8..11 = U2 D7..D4 = Key 9..12
U2 D3..D0 tied to +3V3 (spare, always reads "not pressed").

IO46 is input-only. All are left as no-connect here. U2

J5 = MLX90640 32x24 thermal array (I2C 0x33). It sits on the clock aimed
at the bed and replaces BOTH the mattress accelerometer and the PIR:
frame differencing gives contactless actigraphy, and a warm body-sized
region gives a direct in-bed / out-of-bed reading. No wire to the bed.
10kSW5 Key_3 R8

J6 is now a spare 3-pin header on +5V / IO14 / GND.
J4 INMP441 L/R is tied to GND = LEFT channel.

Size: A4 | Rev:
KiCad E.D.A. 10.0.6 | Id: 1/1

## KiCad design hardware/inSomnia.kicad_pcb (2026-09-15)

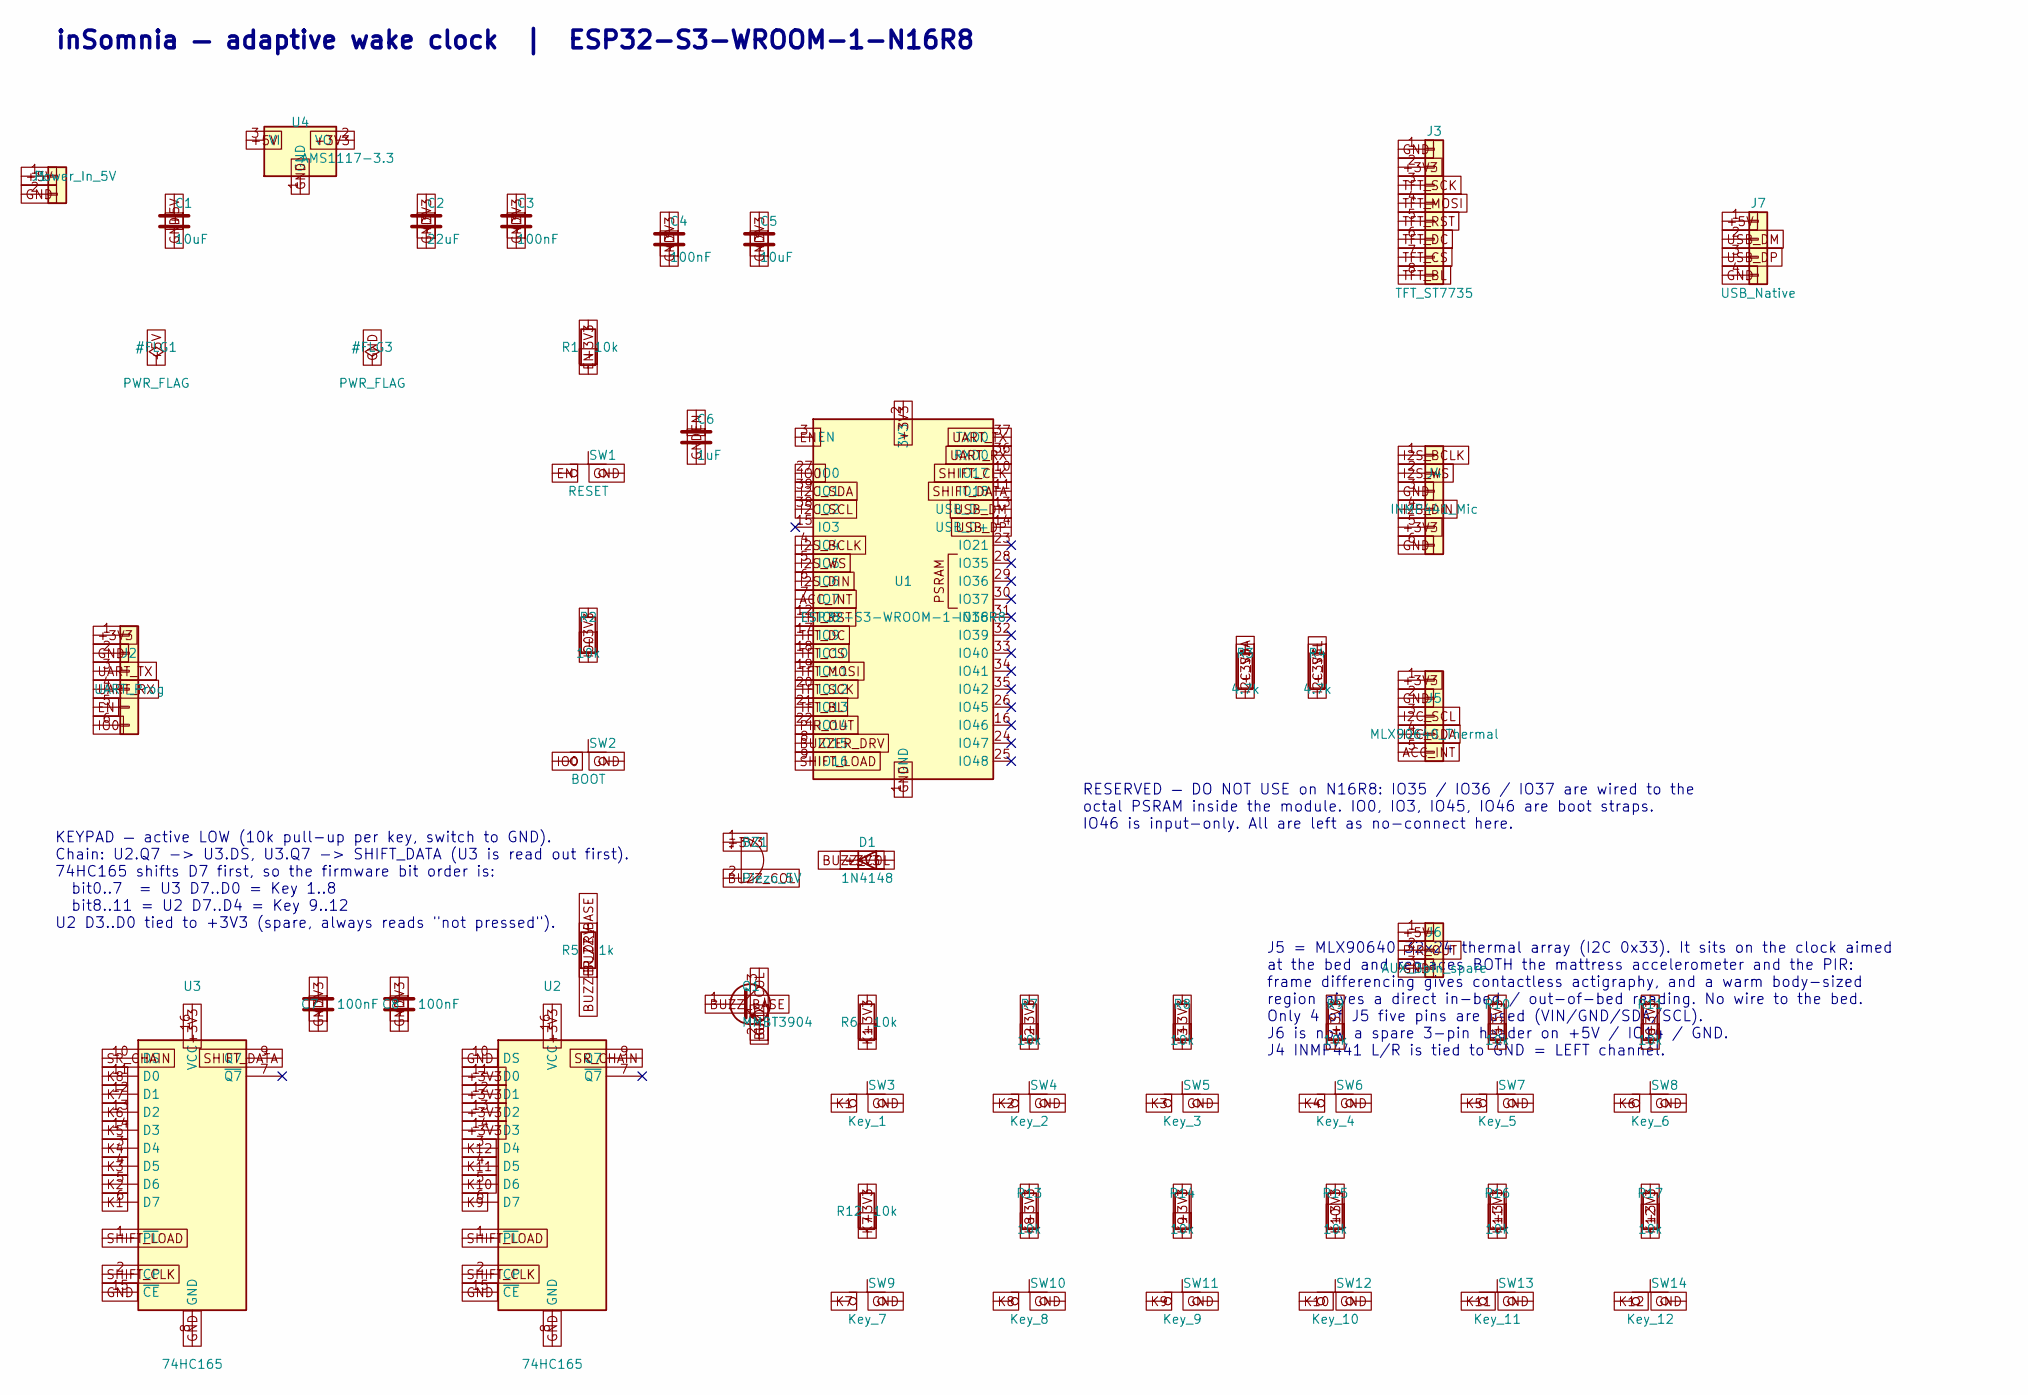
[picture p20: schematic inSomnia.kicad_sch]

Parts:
BZ1: Piezo_5V; Buzzer_TDK_PS1240P02BT_D12.2mm_H6.5mm
C1, C5: 10uF; C_0805_2012Metric
C2: 22uF; C_0805_2012Metric
C3, C4, C7, C8: 100nF; C_0805_2012Metric
C6: 1uF; C_0805_2012Metric
D1: 1N4148; D_SOD-123
J1: Power_In_5V; PinHeader_1x02_P2.54mm_Vertical
J2: UART_Prog; PinHeader_1x06_P2.54mm_Vertical
J3: TFT_ST7735; PinHeader_1x08_P2.54mm_Vertical
J4: INMP441_Mic; PinHeader_1x06_P2.54mm_Vertical
J5: MLX90640_Thermal; PinHeader_1x05_P2.54mm_Vertical
J6: AUX_3pin_spare; PinHeader_1x03_P2.54mm_Vertical
J7: USB_Native; PinHeader_1x04_P2.54mm_Vertical
Q1: MMBT3904; SOT-23
R1, R2, R6, R7, R8, R9, R10, R11, R12, R13, R14, R15, R16, R17: 10k; R_0805_2012Metric
R3, R4: 4.7k; R_0805_2012Metric
R5: 1k; R_0805_2012Metric
SW1: RESET; SW_PUSH_6mm
SW2: BOOT; SW_PUSH_6mm
SW3: Key_1; SW_PUSH_6mm
SW4: Key_2; SW_PUSH_6mm
SW5: Key_3; SW_PUSH_6mm
SW6: Key_4; SW_PUSH_6mm
SW7: Key_5; SW_PUSH_6mm
SW8: Key_6; SW_PUSH_6mm
SW9: Key_7; SW_PUSH_6mm
SW10: Key_8; SW_PUSH_6mm
SW11: Key_9; SW_PUSH_6mm
SW12: Key_10; SW_PUSH_6mm
SW13: Key_11; SW_PUSH_6mm
SW14: Key_12; SW_PUSH_6mm
U1: ESP32-S3-WROOM-1-N16R8; ESP32-S3-WROOM-1
U2, U3: 74HC165; SOIC-16_3.9x9.9mm_P1.27mm
U4: AMS1117-3.3; SOT-223-3_TabPin2

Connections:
+3V3: BZ1.1 (+), C2.1, C3.1, C4.1, C5.1, C7.1, C8.1, D1.1 (K), J2.1, J3.2, J4.5, J5.1, R1.1, R2.1, R3.1, R4.1, R6.1, R7.1, R8.1, R9.1, R10.1, R11.1, R12.1, R13.1, R14.1, R15.1, R16.1, R17.1, U1.2 (3V3), U2.11 (D0), U2.12 (D1), U2.13 (D2), U2.14 (D3), U2.16 (VCC), U3.16 (VCC), U4.2 (VO)
+5V: C1.1, J1.1, J6.1, J7.1, U4.3 (VI)
ACC_INT: J5.5, U1.7 (IO7)
BUZZER_DRV: R5.1, U1.8 (IO15)
BUZZ_BASE: Q1.1 (B), R5.2
BUZZ_COL: BZ1.2 (-), D1.2 (A), Q1.3 (C)
EN: C6.1, J2.5, R1.2, SW1.1, U1.3 (EN)
GND: C1.2, C2.2, C3.2, C4.2, C5.2, C6.2, C7.2, C8.2, J1.2, J2.2, J3.1, J4.3, J4.6, J5.2, J6.3, J7.4, Q1.2 (E), SW1.2, SW2.2, SW3.2, SW4.2, SW5.2, SW6.2, SW7.2, SW8.2, SW9.2, SW10.2, SW11.2, SW12.2, SW13.2, SW14.2, U1.1 (GND), U1.33 (IO40), U1.40 (GND), U1.41 (GND), U2.8 (GND), U2.10 (DS), U2.15 (~CE), U3.8 (GND), U3.15 (~CE), U4.1 (GND)
I2C_SCL: J5.3, R4.2, U1.38 (IO2)
I2C_SDA: J5.4, R3.2, U1.39 (IO1)
I2S_BCLK: J4.1, U1.4 (IO4)
I2S_DIN: J4.4, U1.6 (IO6)
I2S_WS: J4.2, U1.5 (IO5)
IO0: J2.6, R2.2, SW2.1, U1.27 (IO0)
K1: R6.2, SW3.1, U3.6 (D7)
K2: R7.2, SW4.1, U3.5 (D6)
K3: R8.2, SW5.1, U3.4 (D5)
K4: R9.2, SW6.1, U3.3 (D4)
K5: R10.2, SW7.1, U3.14 (D3)
K6: R11.2, SW8.1, U3.13 (D2)
K7: R12.2, SW9.1, U3.12 (D1)
K8: R13.2, SW10.1, U3.11 (D0)
K9: R14.2, SW11.1, U2.6 (D7)
K10: R15.2, SW12.1, U2.5 (D6)
K11: R16.2, SW13.1, U2.4 (D5)
K12: R17.2, SW14.1, U2.3 (D4)
PIR_OUT: J6.2, U1.22 (IO14)
SHIFT_CLK: U1.10 (IO17), U2.2 (CP), U3.2 (CP)
SHIFT_DATA: U1.11 (IO18), U1.16 (IO46), U3.9 (Q7)
SHIFT_LOAD: U1.9 (IO16), U2.1 (~PL), U3.1 (~PL)
SR_CHAIN: U2.9 (Q7), U3.10 (DS)
TFT_BL: J3.8, U1.21 (IO13)
TFT_CS: J3.7, U1.18 (IO10)
TFT_DC: J3.6, U1.17 (IO9)
TFT_MOSI: J3.4, U1.19 (IO11), U1.23 (IO21)
TFT_RST: J3.5, U1.12 (IO8)
TFT_SCK: J3.3, U1.20 (IO12)
UART_RX: J2.4, U1.36 (RXD0)
UART_TX: J2.3, U1.37 (TXD0)
USB_DM: J7.2, U1.13 (USB_D-)
USB_DP: J7.3, U1.14 (USB_D+)

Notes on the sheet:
inSomnia — adaptive wake clock | ESP32-S3-WROOM-1-N16R8
RESERVED — DO NOT USE on N16R8: IO35 / IO36 / IO37 are wired to the octal PSRAM inside the module. IO0, IO3, IO45, IO46 are boot straps. IO46 is input-only. All are left as no-connect here.
KEYPAD — active LOW (10k pull-up per key, switch to GND). Chain: U2.Q7 -> U3.DS, U3.Q7 -> SHIFT_DATA (U3 is read out first). 74HC165 shifts D7 first, so the firmware bit order is: bit0..7 = U3 D7..D0 = Key 1..8 bit8..11 = U2 D7..D4 = Key 9..12 U2 D3..D0 tied to +3V3 (spare, always reads "not presse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
J5 = MLX90640 32x24 thermal array (I2C 0x33). It sits on the clock aimed at the bed and replaces BOTH the mattress accelerometer and the PIR: frame differencing gives contactless actigraphy, and a warm body-sized region gives a direct in-bed / out-of-bed reading. No wire to the bed. Only 4 of J5 fi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

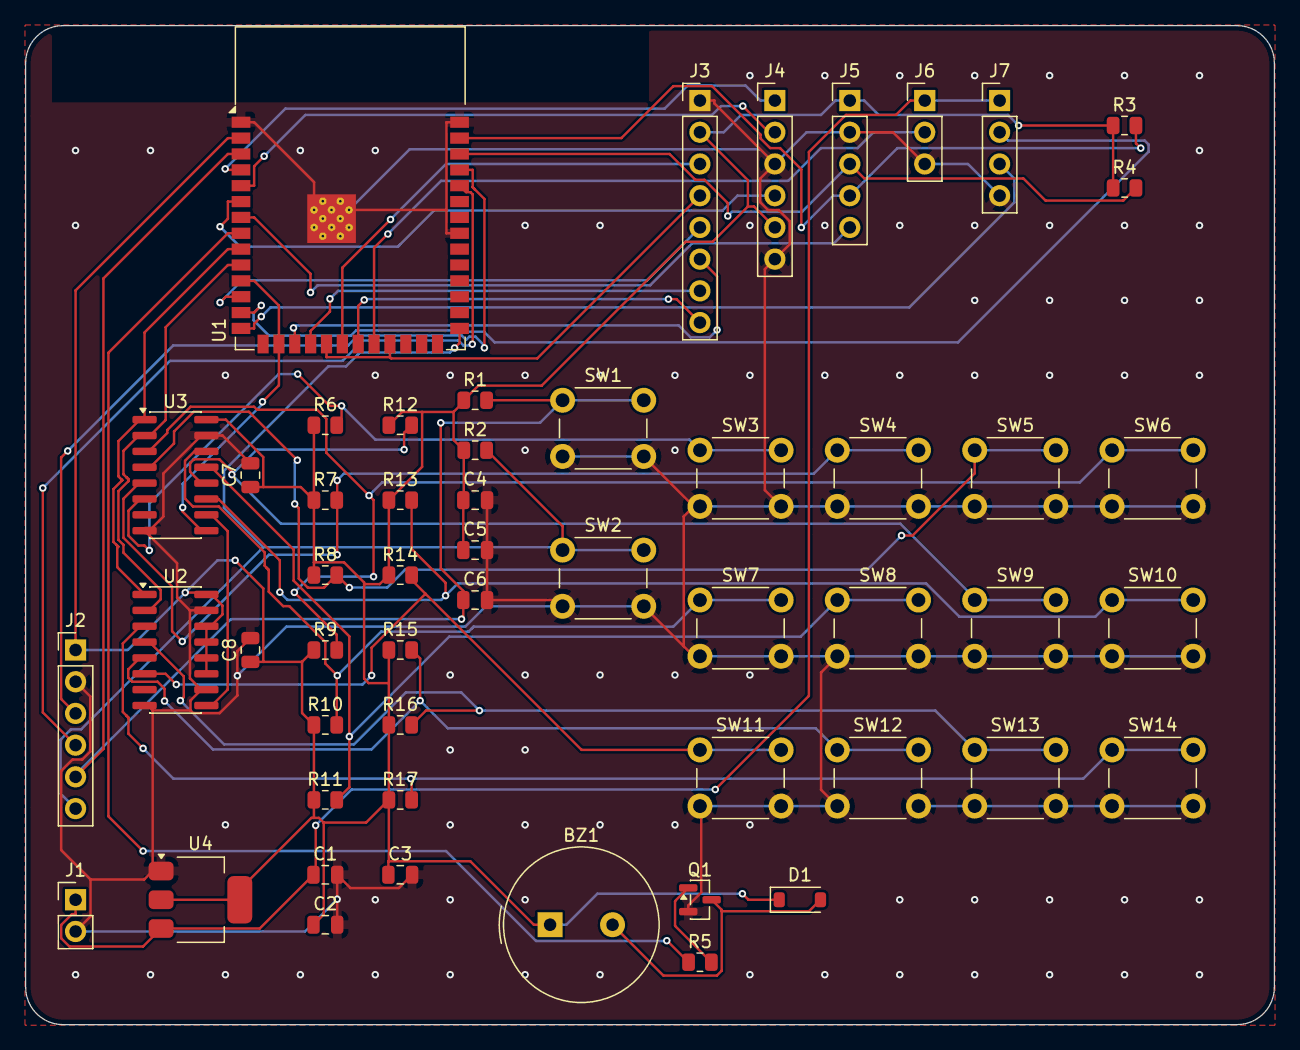
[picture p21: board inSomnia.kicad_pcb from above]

Board: 2 copper layers, 100.0 x 80.0 mm, 53 parts (0 on the bottom side), 41 nets.

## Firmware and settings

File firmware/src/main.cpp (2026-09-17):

// inSomnia — adaptive wake clock
// Phases 1-4: hardware scaffold, network, sensing, sleep-state, alarm logic.

#include <Arduino.h>
#include "config.h"
#include "pin_config.h"
#include "settings.h"
#include "display.h"
#include "buzzer.h"
#include "key_matrix.h"
#include "thermal.h"
#include "mic.h"
#include "sleep_debt.h"
#include "sleep_model.h"
#include "alarm.h"
#include "net.h"
#include "web_ui.h"

#define COL_BG      ST77XX_BLACK
#define COL_DIM     0x4A69
#define COL_TEXT    ST77XX_WHITE
#define COL_ACCENT  0x4D3F
#define COL_OK      0x2FEB
#define COL_WARN    ST77XX_YELLOW
#define COL_ALERT   ST77XX_RED

// ── Keymap ───────────────────────────────────────────────────────────────
// The board carries 12 keys in a 4x3 grid (inherited from the original
// schematic). Layout matches the enclosure: bit 0 is front-left.
//
//   row 1  DISMISS   SNOOZE    LIGHT     SKIP
//   row 2  OPEN -    OPEN +    DEAD -    DEAD +
//   row 3  PAGE      TEST SOFT TEST LOUD SAVE
//
// Row 1 is what you hit half-asleep; rows 2 and 3 are setup you do awake.
#define KEY_DISMISS    0
#define KEY_SNOOZE     1
#define KEY_LIGHT      2
#define KEY_SKIP       3
#define KEY_OPEN_DN    4
#define KEY_OPEN_UP    5
#define KEY_DEAD_DN    6
#define KEY_DEAD_UP    7
#define KEY_PAGE       8
#define KEY_TEST_SOFT  9
#define KEY_TEST_LOUD  10
#define KEY_SAVE       11

enum UiPage { PAGE_STATUS, PAGE_WINDOW, PAGE_DEBT, PAGE_COUNT_ };
static UiPage uiPage = PAGE_STATUS;
static uint32_t toastUntilMs = 0;
static char toast[24] = "";

static void showToast(const char* t) {
    strncpy(toast, t, sizeof(toast)-1);
    toast[sizeof(toast)-1] = 0;
    toastUntilMs = millis() + 1600;
}

static uint16_t clampMin(int32_t v) {
    while (v < 0) v += 1440;
    return (uint16_t)(v % 1440);
}

static uint32_t lastRenderMs = 0;
static uint32_t lastEpochMs = 0;
static char cacheTime[16] = "";
static char cacheState[28] = "";
static char cacheAlarm[28] = "";
static char cacheNet[28] = "";
static char cacheSens[28] = "";

static void runEpoch() {
    uint8_t inBedPct = thermal.epochInBedPercent();
    thermal.rollEpoch();
    mic.rollEpoch();

    float loud = mic.lastEpochLoudFraction();

    uint32_t c = thermal.lastEpochCounts();
    uint16_t counts = (c > 65535) ? 65535 : (uint16_t)c;

    sleepModel.pushEpoch(counts, loud, inBedPct);

    Serial.printf("[epoch] counts=%u loud=%.2f inbed=%u%% warm=%u state=%s oob=%d\n",
                  counts, loud, inBedPct, thermal.warmPixels(),
                  sleepModel.stateName(), sleepModel.outOfBed() ? 1 : 0);
}

static void drawRow(int16_t y, const char* text, uint16_t color,
                    char* cache, size_t cacheLen) {
    if (strncmp(cache, text, cacheLen) == 0) return;
    strncpy(cache, text, cacheLen - 1);
    cache[cacheLen - 1] = '\0';
    display.fillRow(y, 10, COL_BG);
    display.drawText(text, 4, y, color, 1);
}

static bool forceRedraw = false;

static void renderWindowPage() {
    const Settings& c = settings.get();
    char buf[32];
    snprintf(buf, sizeof(buf), "open   %02u:%02u",
             c.windowOpenMin/60, c.windowOpenMin%60);
    drawRow(50, buf, COL_TEXT, cacheState, sizeof(cacheState));
    snprintf(buf, sizeof(buf), "dline  %02u:%02u",
             c.windowDeadlineMin/60, c.windowDeadlineMin%60);
    drawRow(62, buf, COL_TEXT, cacheAlarm, sizeof(cacheAlarm));
    snprintf(buf, sizeof(buf), "debt shift +%um", alarmEngine.debtShiftMinutes());
    drawRow(80, buf, COL_DIM, cacheSens, sizeof(cacheSens));
    drawRow(92, "K12 saves", COL_DIM, cacheNet, sizeof(cacheNet));
}

static void renderDebtPage() {
    char buf[32];
    int32_t cum = sleepDebt.cumulativeDebtMin();
    snprintf(buf, sizeof(buf), "debt  %ldh%02ldm", (long)(cum/60), (long)(cum%60));
    drawRow(50, buf, cum > 120 ? COL_WARN : COL_OK, cacheState, sizeof(cacheState));
    uint16_t avg = sleepDebt.averageSleepMin();
    snprintf(buf, sizeof(buf), "avg   %uh%02um", avg/60, avg%60);
    drawRow(62, buf, COL_DIM, cacheAlarm, sizeof(cacheAlarm));
    snprintf(buf, sizeof(buf), "nights %u/14", sleepDebt.nightsRecorded());
    drawRow(80, buf, COL_DIM, cacheSens, sizeof(cacheSens));
    const NightRecord& n = alarmEngine.lastNight();
    snprintf(buf, sizeof(buf), "last  %uh%02um", n.totalSleepMin/60, n.totalSleepMin%60);
    drawRow(92, buf, COL_DIM, cacheNet, sizeof(cacheNet));
}

static void render() {
    struct tm t;
    bool trusted = false;
    bool hasTime = net.timeForAlarm(&t, &trusted);

    char timeBuf[16];
    if (hasTime) {
        strftime(timeBuf, sizeof(timeBuf), "%H:%M:%S", &t);
        if (!trusted) {
            // append * for estimate
            size_t l = strlen(timeBuf);
            if (l + 1 < sizeof(timeBuf)) { timeBuf[l] = '*'; timeBuf[l+1] = '\0'; }
        }
    } else {
        snprintf(timeBuf, sizeof(timeBuf), "--:--:--");
    }

    if (strcmp(cacheTime, timeBuf) != 0) {
        strncpy(cacheTime, timeBuf, sizeof(cacheTime) - 1);
        display.fillRow(18, 24, COL_BG);
        display.drawTextCentered(timeBuf, 18, trusted ? COL_TEXT : COL_WARN, 3);
    }

    if (forceRedraw) {
        forceRedraw = false;
        cacheState[0] = cacheAlarm[0] = cacheSens[0] = cacheNet[0] = '\x01';
        display.fillRow(48, 58, COL_BG);
    }

    if (millis() < toastUntilMs) {
        display.fillRow(100, 10, COL_BG);
        display.drawText(toast, 4, 100, COL_ACCENT, 1);
    } else if (toast[0]) {
        display.fillRow(100, 10, COL_BG);
        toast[0] = 0;
    }

    if (uiPage == PAGE_WINDOW) { renderWindowPage(); return; }
    if (uiPage == PAGE_DEBT)   { renderDebtPage();   return; }

    char buf[32];
    uint16_t stateCol = COL_DIM;
    switch (sleepModel.state()) {
        case STATE_ASLEEP:   stateCol = COL_OK; break;
        case STATE_STIRRING: stateCol = COL_WARN; break;
        case STATE_AWAKE:    stateCol = COL_ACCENT; break;
        default: break;
    }
    snprintf(buf, sizeof(buf), "%-8s  %5u", sleepModel.stateName(),
             sleepModel.lastCounts());
    drawRow(50, buf, stateCol, cacheState, sizeof(cacheState));

    AlarmPhase ph = alarmEngine.phase();
    int32_t mins = (alarmEngine.minutesToWindowOpen() > 0)
                 ? alarmEngine.minutesToWindowOpen()
                 : alarmEngine.minutesToDeadline();
    const char* lbl = (alarmEngine.minutesToWindowOpen() > 0) ? "open" : "dline";
    snprintf(buf, sizeof(buf), "%-10s %s %ldm",
             alarmEngine.phaseName(), lbl, (long)mins);
    drawRow(62, buf,
            (ph == ALARM_HARD) ? COL_ALERT :
            (ph == ALARM_GENTLE) ? COL_WARN : COL_DIM,
            cacheAlarm, sizeof(cacheAlarm));

    snprintf(buf, sizeof(buf), "th%c mic%c %s%s",
             thermal.healthy() ? '+' : '-',
             mic.healthy() ? '+' : '-',
             thermal.inBed() ? "inbed" : "empty",
             alarmEngine.failsafeActive() ? " FAIL" : "");
    drawRow(80, buf,
            alarmEngine.failsafeActive() ? COL_ALERT : COL_DIM,
            cacheSens, sizeof(cacheSens));

    snprintf(buf, sizeof(buf), "%s", net.isSetupMode()
             ? SETUP_AP_SSID : net.ipAddress().c_str());
    drawRow(92, buf, COL_DIM, cacheNet, sizeof(cacheNet));
}

void setup() {
    Serial.begin(115200);
    delay(300);

    Serial.println();
    Serial.println("inSomnia " FW_VERSION);

    settings.begin();
    display.begin();
    display.setBrightness(settings.get().backlight);
    buzzer.begin();
    keys.begin();
    thermal.begin();
    mic.begin();
    sleepModel.begin();
    sleepDebt.begin();

    {
        const Settings& c = settings.get();
        thermal.setRoi(c.roiX0, c.roiY0, c.roiX1, c.roiY1);
    }

    net.begin();
    webui.begin();
    alarmEngine.begin();

    display.clear(COL_BG);
    display.drawText("inSomnia", 4, 4, COL_ACCENT, 1);
    display.tft().drawFastHLine(0, 15, display.width(), 0x2124);
    display.tft().drawFastHLine(0, 46, display.width(), 0x2124);
    display.tft().drawFastHLine(0, 76, display.width(), 0x2124);
    display.drawText("K1 off K2 snz K9 page", 4, 112, COL_DIM, 1);

    lastEpochMs = millis();
    Serial.printf("[boot] heap %u, thermal=%d mic=%d, debt %ld min over %u nights\n",
                  ESP.getFreeHeap(), thermal.present(), mic.present(),
                  (long)sleepDebt.cumulativeDebtMin(), sleepDebt.nightsRecorded());
}

void loop() {
    net.loop();
    webui.loop();
    keys.update();
    thermal.update();
    mic.update();

    Settings& cfg = settings.get();
    if (keys.wasJustPressed(KEY_DISMISS)) { alarmEngine.dismiss(); showToast("dismissed"); }
    if (keys.wasJustPressed(KEY_SNOOZE))  { alarmEngine.snooze();  showToast("snoozed"); }
    if (keys.wasJustPressed(KEY_LIGHT)) {
        static const uint8_t steps[] = {0, 20, 60, 140, 255};
        uint8_t i = 0;
        for (uint8_t k = 0; k < 5; k++) if (cfg.backlight >= steps[k]) i = k;
        cfg.backlight = steps[(i + 1) % 5];
        display.setBrightness(cfg.backlight);
        showToast("light");
    }
    if (keys.wasJustPressed(KEY_SKIP))   { alarmEngine.skipTonight(); showToast("skip tonight"); }

    if (keys.wasJustPressed(KEY_OPEN_DN)) { cfg.windowOpenMin = clampMin((int32_t)cfg.windowOpenMin - 5); uiPage = PAGE_WINDOW; }
    if (keys.wasJustPressed(KEY_OPEN_UP)) { cfg.windowOpenMin = clampMin((int32_t)cfg.windowOpenMin + 5); uiPage = PAGE_WINDOW; }
    if (keys.wasJustPressed(KEY_DEAD_DN)) { cfg.windowDeadlineMin = clampMin((int32_t)cfg.windowDeadlineMin - 5); uiPage = PAGE_WINDOW; }
    if (keys.wasJustPressed(KEY_DEAD_UP)) { cfg.windowDeadlineMin = clampMin((int32_t)cfg.windowDeadlineMin + 5); uiPage = PAGE_WINDOW; }

    if (keys.wasJustPressed(KEY_PAGE))      { uiPage = (UiPage)((uiPage + 1) % PAGE_COUNT_); forceRedraw = true; }
    if (keys.wasJustPressed(KEY_TEST_SOFT)) { alarmEngine.testGentle(); showToast("test: soft"); }
    if (keys.wasJustPressed(KEY_TEST_LOUD)) {
        if (alarmEngine.phase() == ALARM_HARD || alarmEngine.phase() == ALARM_GENTLE) {
            alarmEngine.stopTest(); showToast("test stopped");
        } else { alarmEngine.testHard(); showToast("test: loud"); }
    }
    if (keys.wasJustPressed(KEY_SAVE))      { settings.save(); showToast("saved"); }

    uint32_t now = millis();
    if (now - lastEpochMs >= (uint32_t)EPOCH_SECONDS * 1000UL) {
        lastEpochMs = now;
        runEpoch();
    }

    alarmEngine.update();

    if (now - lastRenderMs >= 250) {
        lastRenderMs = now;
        render();
    }
}

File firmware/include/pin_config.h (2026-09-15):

#pragma once

// inSomnia pin map — ESP32-S3-WROOM-1-N16R8
// Matches hardware/inSomnia.kicad_sch (ERC clean).
//
// RESERVED, never assign on the N16R8 part:
//   IO35 / IO36 / IO37  -> octal PSRAM inside the module
//   IO0 / IO3 / IO45 / IO46 -> boot straps (IO46 is also input-only)
//   IO19 / IO20 -> native USB D-/D+
// All of the above are left as no-connect on the schematic.

// ── TFT ST7735 128x160 (SPI, remapped via the GPIO matrix) ────────
#define TFT_SCK     12
#define TFT_MOSI    11
#define TFT_CS      10
#define TFT_DC      9
#define TFT_RST     8
#define TFT_BL      13

// ── INMP441 I2S MEMS microphone ──────────────────────────────────
#define I2S_BCLK    4
#define I2S_WS      5
#define I2S_DIN     6
#define I2S_PORT    I2S_NUM_0

// ── MLX90640 32x24 thermal array (I2C) ───────────────────────────
// Sits on the clock, aimed at the bed. Replaces both the mattress
// accelerometer and the PIR: it gives contactless actigraphy AND a direct
// in-bed / out-of-bed measurement, with no wire running to the bed.
#define I2C_SDA       1
#define I2C_SCL       2
#define THERM_INT     7    // spare, MLX90640 breakout does not need it
#define MLX90640_ADDR 0x33

// ── Spare (was PIR; the thermal array supersedes it) ─────────────
#define AUX_GPIO    14

// ── Buzzer (via MMBT3904 NPN, active high) ───────────────────────
#define BUZZER_PIN  15

// ── 74HC165 keypad shift chain ───────────────────────────────────
#define SHIFT_LOAD  16
#define SHIFT_CLK   17
#define SHIFT_DATA  18

// ── Panel geometry ───────────────────────────────────────────────
#define TFT_PANEL_W     128
#define TFT_PANEL_H     160
#define TFT_ROTATION    1     // landscape -> 160 wide x 128 tall

// ── LEDC ─────────────────────────────────────────────────────────
// timer = (channel / 2) % 4, so channels 0 and 1 share timer 0.
// Backlight must not share a timer with the buzzer.
#define BUZZER_CHANNEL       0   // timer 0
#define BACKLIGHT_CHANNEL    2   // timer 1
#define BUZZER_RESOLUTION    8
#define BUZZER_IDLE_FREQ     2000
#define BACKLIGHT_FREQ       5000
#define BACKLIGHT_RESOLUTION 8

// ── Keypad ───────────────────────────────────────────────────────
// Chain: U2.Q7 -> U3.DS, U3.Q7 -> SHIFT_DATA. U3 is clocked out first,
// and the 74HC165 presents D7 first, so:
//   bit0..7  = U3 D7..D0 = Key 1..8
//   bit8..11 = U2 D7..D4 = Key 9..12
#define NUM_SHIFT_REGS   2
#define NUM_KEY_BITS     (NUM_SHIFT_REGS * 8)
#define NUM_KEYS         12
#define KEY_ACTIVE_LOW   1
#define KEY_DEBOUNCE_MS  25

// ── PIR sampling (Phase 1 proxy; Phase 3 replaces the classifier) ──
#define PIR_SAMPLE_INTERVAL_MS  1000
#define PIR_WINDOW_SAMPLES      300

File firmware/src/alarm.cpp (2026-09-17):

#include "alarm.h"
#include "settings.h"
#include "buzzer.h"
#include "net.h"
#include "thermal.h"
#include "mic.h"
#include "sleep_debt.h"
#include "config.h"
#include <Preferences.h>

AlarmEngine alarmEngine;
static Preferences aprefs;

#define GENTLE_TONE_HZ   880
#define HARD_TONE_HZ     3200
#define GENTLE_PERIOD_MS 2600
#define GENTLE_BEEP_MS   420
#define HARD_PERIOD_MS   700
#define HARD_BEEP_MS     380
#define SUPPRESS_CONFIRM_SEC 120

AlarmEngine::AlarmEngine()
    : _phase(ALARM_IDLE), _outcome(OUTCOME_NONE), _failsafe(false), _volume(0),
      _phaseEnteredMs(0), _lastBeepMs(0), _beepOn(false), _minsToOpen(0),
      _minsToDeadline(0), _lastYday(-1), _snoozeUntilMs(0), _testMode(false), _debtShift(0) {
    memset(&_lastNight, 0, sizeof(_lastNight));
}

void AlarmEngine::begin() {
    loadLastNight();
    enter(ALARM_ARMED);
}

void AlarmEngine::enter(AlarmPhase p) {
    if (_phase == p) return;
    _phase = p;
    _phaseEnteredMs = millis();
    _beepOn = false;
    if (p != ALARM_GENTLE && p != ALARM_HARD) {
        _volume = 0;
        buzzer.stop();
    }
    Serial.printf("[alarm] -> %s\n", phaseName());
}

bool AlarmEngine::sensorsUsable() const {
    // The thermal array is the load-bearing sensor. The mic alone cannot tell
    // whether you are in the bed, so it is not a substitute.
    return thermal.healthy();
}

void AlarmEngine::update() {
    const Settings& cfg = settings.get();

    struct tm t;
    bool trusted = false;
    if (!net.timeForAlarm(&t, &trusted)) {
        _failsafe = true;
        if (_phase == ALARM_GENTLE || _phase == ALARM_HARD) driveOutput();
        return;
    }
    if (!trusted) {
        // Offline estimate — still run the alarm, but mark degraded so debug is honest.
        // This is what makes the clock fail-safe, not fail-silent, when offline.
        static uint32_t lastWarn = 0;
        if (millis() - lastWarn > 60000) {
            lastWarn = millis();
            Serial.println("[alarm] time estimate (NTP not yet synced), running on fallback clock");
        }
    }

    uint16_t nowMin = t.tm_hour * 60 + t.tm_min;

    if (_lastYday != t.tm_yday) {
        _lastYday = t.tm_yday;
        _outcome = OUTCOME_NONE;
        _snoozeUntilMs = 0;
        _testMode = false;
        sleepModel.resetNight();
        enter(ALARM_ARMED);
        Serial.println("[alarm] new day, re-armed");
    }

    // Sleep-debt-aware waking: when you are carrying debt, hold the gentle
    // wake back a little so an early stir does not cost you the lie-in. The
    // hard deadline never moves -- debt can delay the nudge, never the alarm.
    _debtShift = sleepDebt.wakeShiftMinutes();
    uint16_t effectiveOpen = cfg.windowOpenMin + _debtShift;
    if (effectiveOpen > cfg.windowDeadlineMin) effectiveOpen = cfg.windowDeadlineMin;

    _minsToOpen = (int32_t)effectiveOpen - (int32_t)nowMin;
    _minsToDeadline = (int32_t)cfg.windowDeadlineMin - (int32_t)nowMin;

    // Fail SAFE, never fail silent: if the sensors are gone we stop trusting
    // stirring detection and suppression, and degrade to a plain fixed-time
    // alarm at the hard deadline.
    _failsafe = !sensorsUsable();
    sleepModel.setDegraded(_failsafe);

    if (_testMode) { driveOutput(); return; }

    if (!cfg.alarmEnabled) {
        if (_phase != ALARM_IDLE) enter(ALARM_IDLE);
        return;
    }

    switch (_phase) {
        case ALARM_IDLE:
            enter(ALARM_ARMED);
            break;

        case ALARM_ARMED:
            if (_minsToOpen > 0) {
                // Before the window: suppress only on the blunt out-of-bed
                // signal, never on the sleep classifier alone.
                if (cfg.suppressEnabled && !_failsafe &&
                    sleepModel.outOfBed() &&
                    sleepModel.state() == STATE_AWAKE &&
                    sleepModel.secondsInState() >= SUPPRESS_CONFIRM_SEC) {
                    recordOutcome(OUTCOME_SUPPRESSED);
                    enter(ALARM_SUPPRESSED);
                }
            } else if (_minsToDeadline > 0) {
                // Inside the window.
                if (!_failsafe && (sleepModel.state() == STATE_STIRRING ||
                                   sleepModel.state() == STATE_AWAKE)) {
                    enter(ALARM_GENTLE);
                }
            } else {
                enter(ALARM_HARD);
            }
            break;

        case ALARM_SUPPRESSED:
            // Stays suppressed for the rest of this day's window.
            if (_minsToDeadline < 0) enter(ALARM_DONE);
            break;

        case ALARM_GENTLE:
            if (_minsToDeadline <= 0) enter(ALARM_HARD);
            break;

        case ALARM_HARD:
            break;

        case ALARM_SNOOZED:
            if (millis() >= _snoozeUntilMs) enter(ALARM_HARD);
            break;

        case ALARM_DONE:
            break;
    }

    driveOutput();
}

void AlarmEngine::driveOutput() {
    const Settings& cfg = settings.get();
    uint32_t now = millis();

    if (_phase != ALARM_GENTLE && _phase != ALARM_HARD) {
        if (_beepOn) { buzzer.stop(); _beepOn = false; }
        return;
    }

    uint16_t tone;
    uint32_t period, onMs;

    if (_phase == ALARM_GENTLE) {
        uint32_t elapsedMin = (now - _phaseEnteredMs) / 60000UL;
        uint8_t span = (cfg.hardVol > cfg.gentleStartVol)
                     ? (cfg.hardVol - cfg.gentleStartVol) : 0;
        uint32_t ramp = cfg.gentleRampMin ? cfg.gentleRampMin : 1;
        uint32_t add = (elapsedMin >= ramp) ? span : (span * elapsedMin) / ramp;
        _volume = cfg.gentleStartVol + (uint8_t)add;
        tone = GENTLE_TONE_HZ;
        period = GENTLE_PERIOD_MS;
        onMs = GENTLE_BEEP_MS;
    } else {
        _volume = cfg.hardVol;
        tone = HARD_TONE_HZ;
        period = HARD_PERIOD_MS;
        onMs = HARD_BEEP_MS;
    }

    uint32_t inCycle = (now - _phaseEnteredMs) % period;
    bool shouldBeOn = inCycle < onMs;

    if (shouldBeOn && !_beepOn) {
        buzzer.playTone(tone, _volume);
        _beepOn = true;
    } else if (!shouldBeOn && _beepOn) {
        buzzer.stop();
        _beepOn = false;
    } else if (shouldBeOn && _beepOn) {
        buzzer.playTone(tone, _volume);
    }
}

void AlarmEngine::dismiss() {
    if (_testMode) { stopTest(); return; }
    if (_phase == ALARM_GENTLE) recordOutcome(OUTCOME_STIRRED_WOKE);
    else if (_phase == ALARM_HARD)
        recordOutcome(_failsafe ? OUTCOME_FAILSAFE : OUTCOME_HARD_WOKE);
    enter(ALARM_DONE);
}

void AlarmEngine::snooze() {
    if (_testMode) { stopTest(); return; }
    if (_phase != ALARM_GENTLE && _phase != ALARM_HARD) return;
    _snoozeUntilMs = millis() + (uint32_t)settings.get().snoozeMin * 60000UL;
    enter(ALARM_SNOOZED);
}

void AlarmEngine::skipTonight() {
    // Manual override: you already know you're getting up, so don't ring at all.
    recordOutcome(OUTCOME_SUPPRESSED);
    enter(ALARM_SUPPRESSED);
}
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

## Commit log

2026-09-15 inSomnia: adaptive, context-aware wake clock
    An alarm clock that wakes you inside a window at a moment you're already
    stirring, and stays quiet if you got up before the window opened.
    Hardware (ESP32-S3-WROOM-1-N16R8, 100x80mm 2-layer):
    - MLX90640 32x24 thermal array on the clock, aimed at the bed. Frame
    differencing gives a contactless motion index; a warm body-sized region
    gives in-bed / out-of-bed directly. No wire to the bed, works in darkness,
    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
    [inSomnia-B_Courtyard.gbr, inSomnia-B_Cu.gbl, inSomnia-B_Fab.gbr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]
2026-09-15 Add concept render of the enclosure
    Blender/Eevee product shot of the intended inSomnia enclosure: wedge body
    sized to the 100x80mm board, 4x3 keypad on the top face, MLX90640 thermal
    lens on the front lip, and the display showing the stirring state inside the
    wake window. Labelled in the README as a concept render, not a photo -- no
    hardware has been built.
2026-09-15 Add FreeCAD enclosure, matched Blender render, and devlog diagrams
    Enclosure designed parametrically in FreeCAD, with every feature driven off
    the real KiCad component coordinates rather than eyeballed:
    - 106 x 86 x 54mm shell, 2.5mm walls, 101 x 81mm cavity for the 100 x 80 board
    - wedge profile with the display face sloped 44.1 degrees
    - display window corrected to 36 x 29mm: a 1.8in ST7735's ACTIVE AREA is only
    ~35 x 28mm, far smaller than the module outline the earlier mock assumed
    - 12 keypad holes at the real SW3..SW14 positions, accounting for the
    SW_PUSH_6mm footprint anchor not being centred
    - thermal aperture, buzzer grille, rear cable exit, regulator vents, M2 bosses
    - STEP +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
    [inSomnia_base_plate.step, inSomnia_base_plate.stl, inSomnia_case.FCStd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]
2026-09-15 Give all 12 keys a function; render from the real CAD mesh in local Blender
    The board has 12 keys and the firmware used 2. Assigned the other ten:
    row 1 DISMISS SNOOZE LIGHT SKIP
    row 2 OPEN - OPEN + DEAD - DEAD +
    row 3 PAGE SOFT LOUD SAVE
    Row 1 is the half-asleep row. Rows 2-3 adjust the window and deadline in
    5-minute steps, page between status/window/debt screens, test the alarm and
    save to flash. Adds a display page system, toast feedback, and
    AlarmEngine::skipTonight() as the manual form of context-aware silence.
    Rendering moved off the cloud 3D service onto local Blender via the BlenderMCP
    addon already running on 127.0.0.1:9876. This removes the hand-copied
    d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
    [inSomnia_scene.blend]
2026-09-17 forge: offline fallback clock, snooze fix, BOM with cost, wiring + case renders
    - net: fallback clock via millis() so alarm never fails silent without WiFi
    - alarm: snooze via millis() (wrap-safe), timeForAlarm()
    - display/web: show * for estimated time
    - README: personal why, 7-step how-to, wiring diagram, updated stats
    - BOM: LCSC links + modules (MLX90640/INMP441/ST7735) + TOTAL $68.62
    - HARDWARE: concrete retention via cavity+lip+base plate, DRC 0
    - images: copy board 3D + schematic to hardware/render, case views to hardware/case
    [inSomnia_bom.csv]
